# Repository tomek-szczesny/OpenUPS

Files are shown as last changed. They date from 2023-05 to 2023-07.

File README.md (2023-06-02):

# OpenUPS

A universal and versatile high power SBC UPS

## Introduction

**This is a work in progress repository**

More up-to-date information available on Odroid forum:

[Open source UPS design - ODROID](https://forum.odroid.com/viewtopic.php?f=55&t=46481)

License:

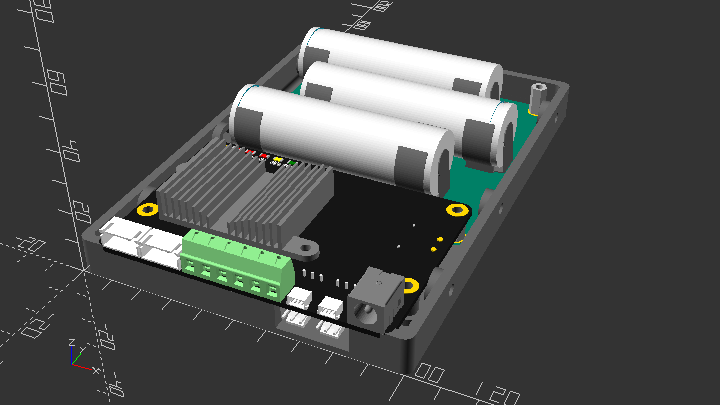
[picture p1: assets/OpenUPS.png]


### Install
```
  git clone https://github.com/tomek-szczesny/OpenUPS.git

```

### OpenUPS Features:
-  Multi SBC support
-  Wide Input Voltage Range: 12V - 24V
-  Multiple Output Voltages: 5V, 12V, Programmable (0-24V) or Vin repeater,
-  Dual SATA power ports, supports 3.5" HDDs as well,
-  Dual 12V Fan ports with PWM control and RPM monitoring,
-  I2C Configuration and Reporting, incl. Battery Voltage, Current
-  3D-printable Custom Cases
   - Drive Bay Case Mount
   - Standalone Case
-  Expandable 3S1P Battery Capacity
-  18650, 20700 or 21700 Cell Support
-  Easy Battery Maintenance

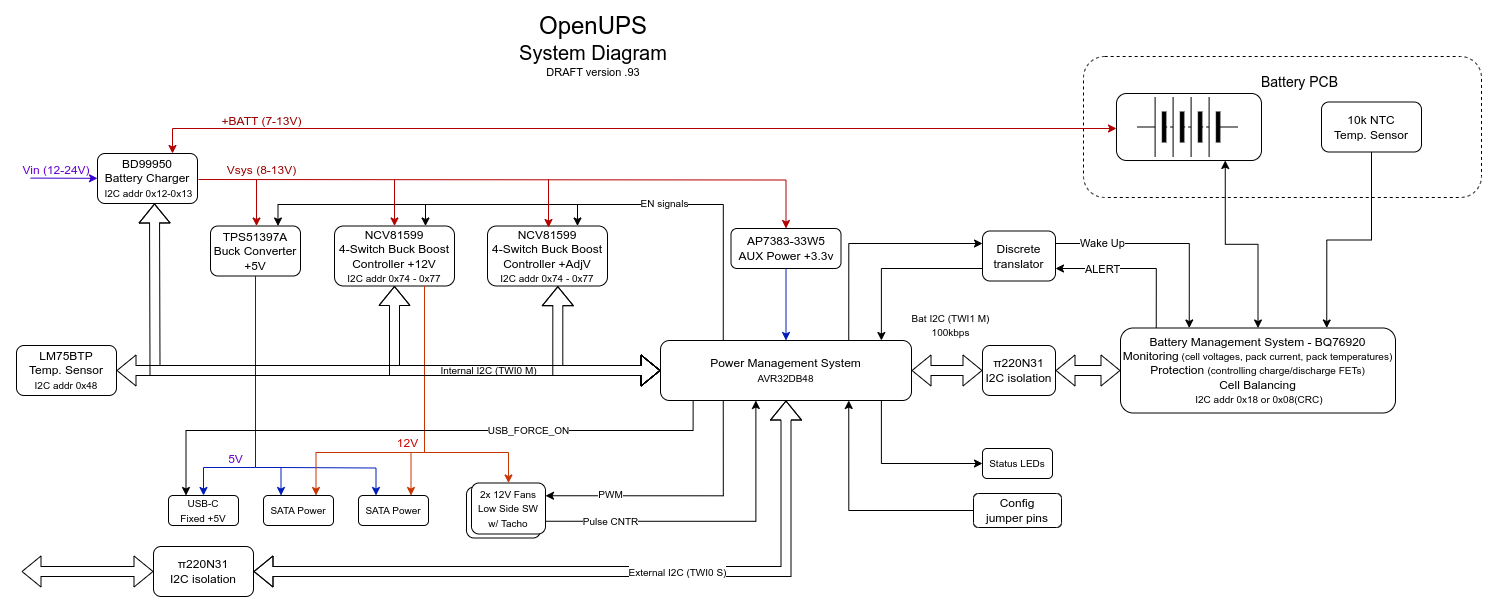
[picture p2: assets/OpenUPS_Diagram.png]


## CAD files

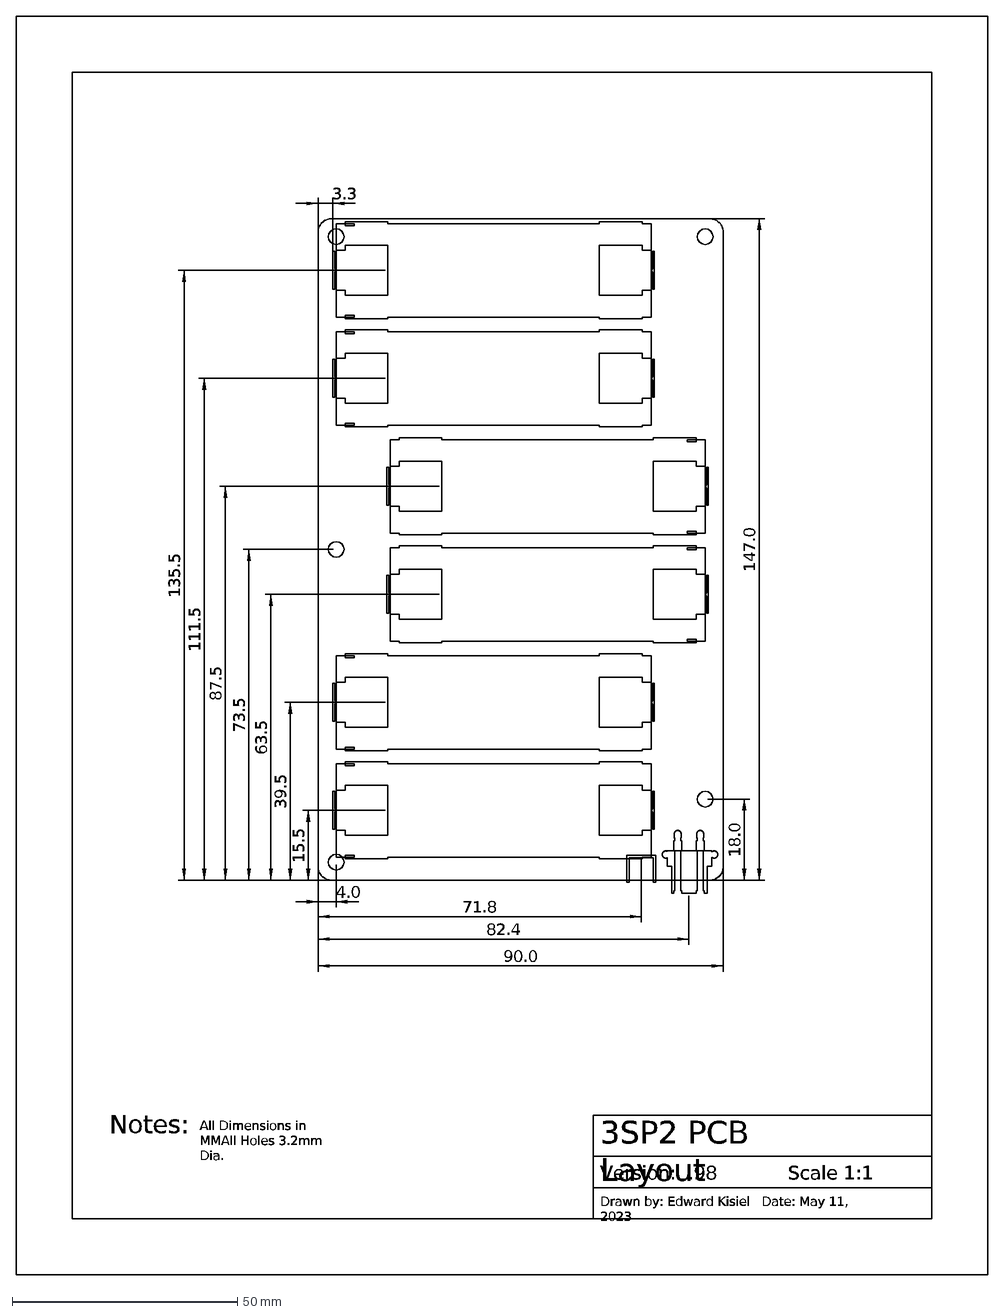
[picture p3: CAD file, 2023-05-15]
case/3S2P_Battery_PCB.dxf
4.0
71.8
82.4
15.5
39.5
63.5
73.5
87.5
111.5
135.5
18.0
3.3
90.0
147.0
Notes:
Version: .98 Scale 1:1
3SP2 PCB Layout
Drawn by: Edward Kisiel Date: May 11, 2023
All Dimensions in MM All Holes 3.2mm Dia.

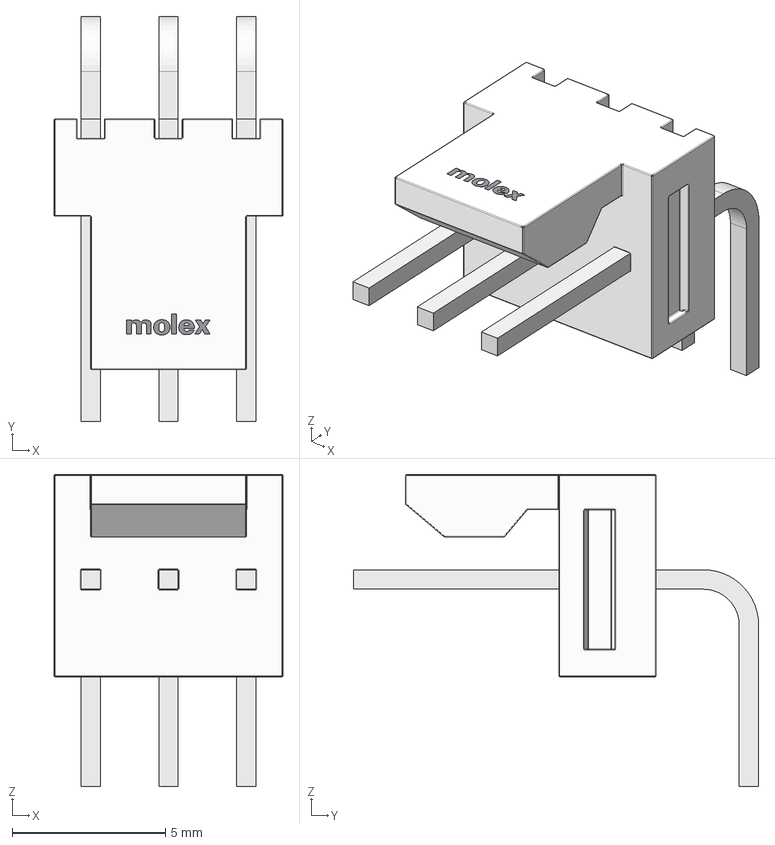
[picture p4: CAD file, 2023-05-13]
hw/OpenUPS_ups/3d/Molex_-_22-05-3031.step
7.47 x 13.2 x 10.2 mm
Molex

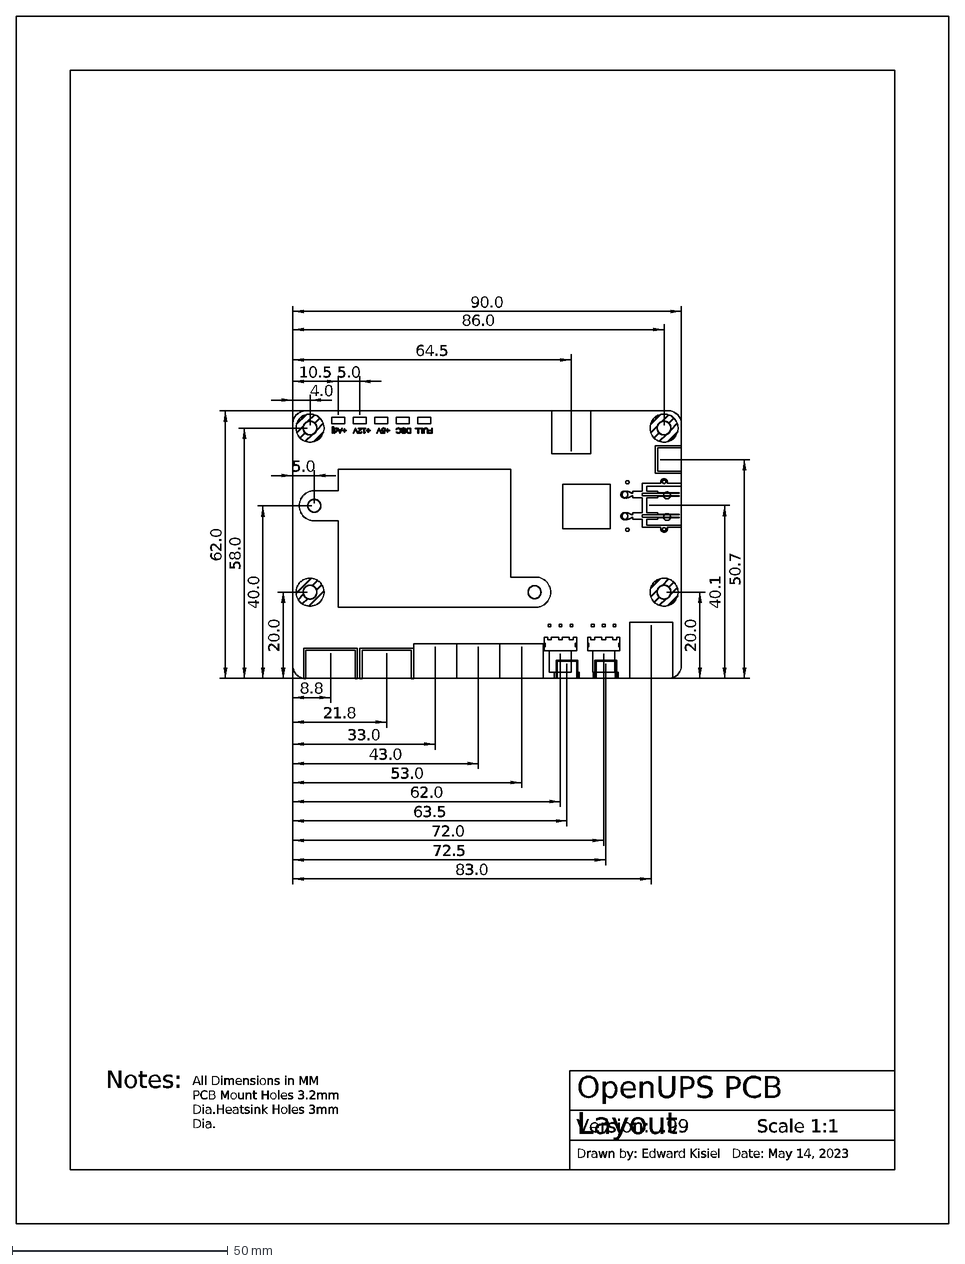
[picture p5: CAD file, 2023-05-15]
case/OpenUPS_PCB.dxf
40.0
58.0
62.0
4.0
5.0
20.0
63.5
72.5
OpenUPS PCB Layout
Notes:
10.5
86.0
90.0
72.0
All Dimensions in MM PCB Mount Holes 3.2mm Dia. Heatsink Holes 3mm Dia.
Version: .99 Scale 1:1
Drawn by: Edward Kisiel Date: May 14, 2023
8.8
21.8
33.0
43.0
53.0
83.0
40.1
50.7
64.5

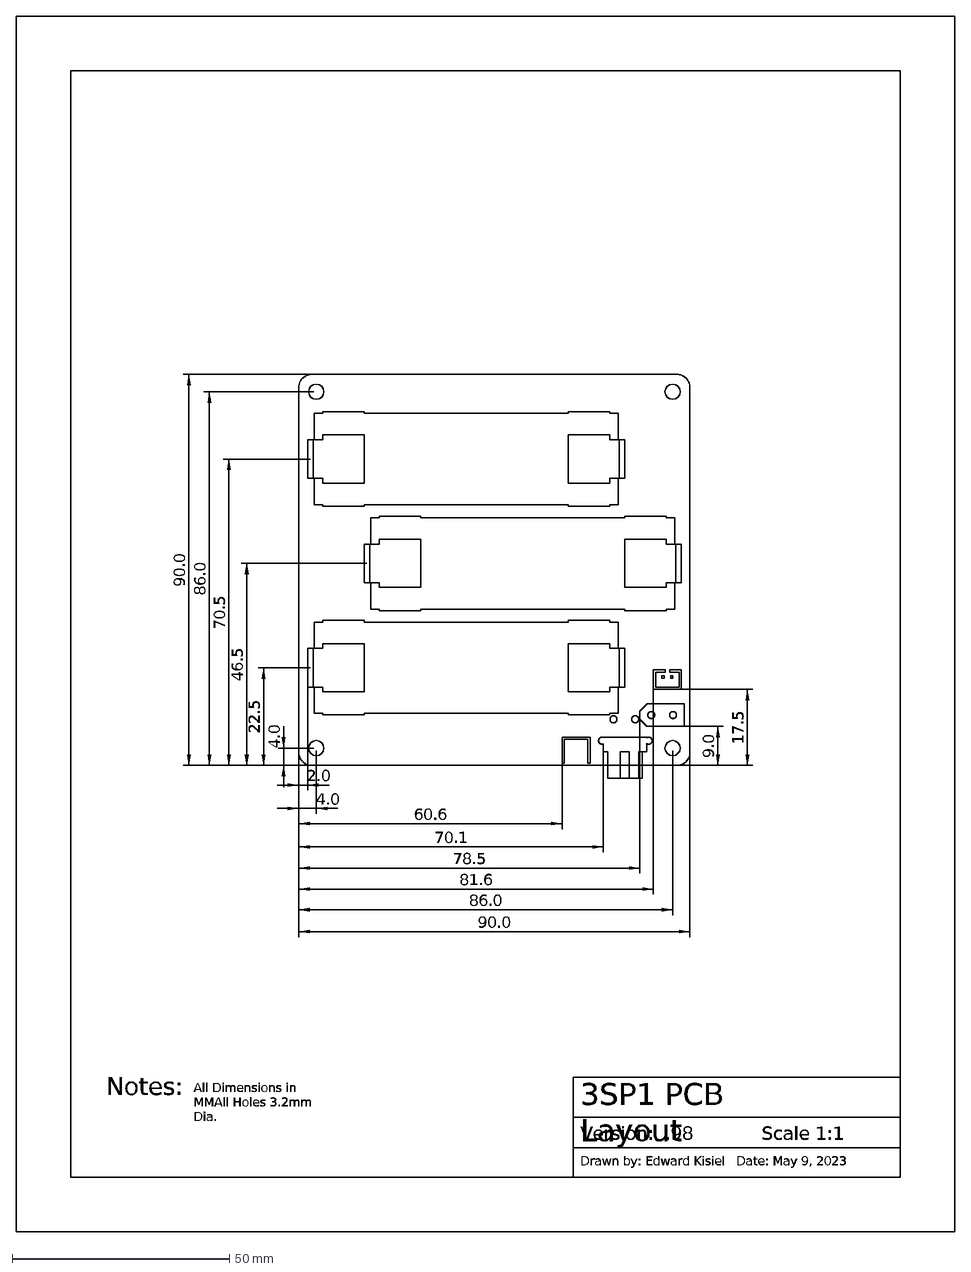
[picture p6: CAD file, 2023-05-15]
case/3S1P_Battery_PCB.dxf
2.0
4.0
60.6
70.1
78.5
81.6
86.0
22.5
46.5
70.5
90.0
Notes:
Version: .98 Scale 1:1
Drawn by: Edward Kisiel Date: May 9, 2023
3SP1 PCB Layout
9.0
17.5
All Dimensions in MM All Holes 3.2mm Dia.

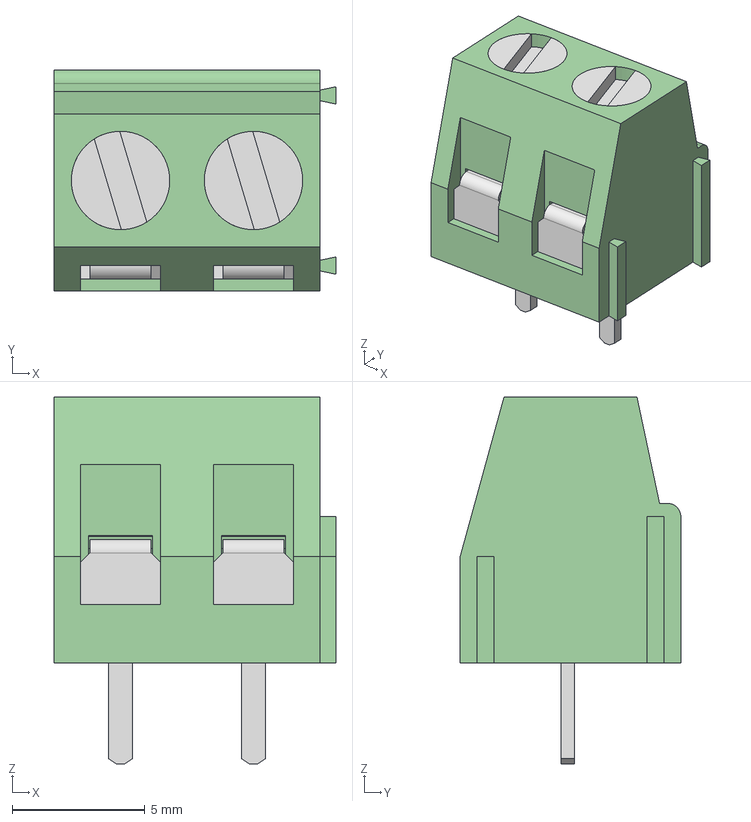
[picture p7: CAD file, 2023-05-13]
hw/OpenUPS_ups/3d/691213710002 (rev1).stp
10.6 x 8.30 x 13.8 mm
6912137100xx_MASS x 2
6912137100xx_VIS x 2
6912137100xx_PIN x 2

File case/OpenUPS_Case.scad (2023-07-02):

/*
    OpenUPS Case Copyright 2023 Edward A. Kisiel hominoid@cablemi.com

    This program is free software: you can redistribute it and/or modify
    it under the terms of the GNU General Public License as published by
    the Free Software Foundation, either version 3 of the License, or
    (at your option) any later version.

    but WITHOUT ANY WARRANTY; without even the implied warranty of
    MERCHANTABILITY or FITNESS FOR A PARTICULAR PURPOSE.  See the
    GNU General Public License for more details.

    You should have received a copy of the GNU General Public License
    along with this program.  If not, see <http://www.gnu.org/licenses/>.
    Code released under GPLv3: http://www.gnu.org/licenses/gpl.html

    202304xx version 0.9 OpenUPS Case
    
    drivebay_ups_top(length=147, width=101.6, bottom_height=12, top_height=14, wallthick, floorthick,
                     pcbsize, pcb_position, batpcbsize, batpcb_position)    
    drivebay_ups_bottom(length=147,width=101.6, bottom_height=12, wallthick, floorthick,
                        pcbsize, pcb_position, batpcbsize, batpcb_position)
    ups_pcb(pcbsize, pcb_position)
    bat_pcb(batpcbsize, batpcb_position)
    battery_placement(bat_layout, bat_num, bat_space, bat_type, bat_dia, bat_len)
    battery_clip(bat_dia = 18.4)
    led(ledcolor = "red")
    battery(type)
    jst_xh(num_pin)
    jst_sh(num_pin)
    jst_ph(num_pin)
    standoff([radius,height,holesize,supportsize,supportheight,sink,style,i_dia,i_depth])
    slab(size, radius)
    slot(hole,length,depth)
    fan_mask(size, thick, style)
    heatsink(type,soc1size_z)xt60(style)
    xt30(style)
    
*/

use <./lib/fillets.scad>;

/* [OpenUPS Case Configuration] */
view = "model"; // ["model", "platter"]
top_enable = true;
bottom_enable = true;
all_connectors = false;
case_style = "drivebay"; // ["drivebay", "mini", "3S1P", "3S2P"]
heatsink_type = "c4_oem"; // ["c4_oem", "xu4_oem"]

ups_pcb_enable = true;
ups_pcb_kicad_model = false;
battery_pcb_enable = true;
rear_wire_feed = false;
bottom_vent = true;
top_vent = true;

bat_num = 3; // [3:3:6]
bat_type = "21700"; // ["18650", "21700"]
bat_layout = "3S_staggered"; // ["straight", "staggered", "3S2P_staggered", "3S_staggered"]
bat_space = 3; // [3:10]

bat_dia = bat_type == "21700" ? 21 : 18.4;
bat_len = bat_type == "21700" ? 70 : 65;

/* [Hidden] */
adj = .01;
$fn = 90;

if(view == "model") {
    if(case_style == "drivebay") {
        // pcb size and placement
        pcbsize = [96, 64, 1.6];
        pcb_position = [2.75, 0, 10];
        batpcbsize = [90, 90, 1];
        batpcb_position = [6, 54, 1];
        bat_position = ([batpcb_position[0]+4,batpcb_position[1]+12,batpcb_position[2]+batpcbsize[2]]);

        if(bottom_enable) {
            color("dimgrey") drivebay_ups_bottom(147, 101.6, 12, 2, 2, 
                pcbsize, pcb_position, batpcbsize, batpcb_position);
        }
        if(top_enable) {
            color("dimgrey") drivebay_ups_top(147, 101.6, 12, 14, 2, 1, 
                pcbsize, pcb_position, batpcbsize, batpcb_position);
        }
        if(ups_pcb_enable) {
            ups_pcb(pcbsize, pcb_position);
        }
        if(ups_pcb_kicad_model) {
            translate([-77,134,10.8]) rotate([0,0,0]) import("lib/OpenUPS_ups.stl");
        }
        if(battery_pcb_enable) {
            bat_pcb(batpcbsize, batpcb_position, bat_position);
            translate(bat_position) battery_placement(bat_layout, bat_num, bat_space, bat_type, bat_dia, bat_len);
            // pillars
            translate([batpcb_position[0]+4, batpcb_position[1]+6,  batpcb_position[2]+batpcbsize[2]]) pillar(5, 8, 0);
            translate([batpcb_position[0]+batpcbsize[0]-4, batpcb_position[1]+6,  batpcb_position[2]+batpcbsize[2]]) 
                pillar(5, 8, 0);
            translate([batpcb_position[0]+4, batpcb_position[1]+batpcbsize[1]-4, batpcb_position[2]+batpcbsize[2]]) 
                pillar(5, 10, 0);
            translate([batpcb_position[0]+batpcbsize[0]-4, batpcb_position[1]+batpcbsize[1]-4, 
                batpcb_position[2]+batpcbsize[2]]) pillar(5, 10, 0);
        }
    }
    if(case_style == "mini") {
        // pcb size and placement
        pcbsize = [96, 64, 1.6];
        pcb_position = [2.75, 0, 10.4];
        batpcbsize = [90, 82, 1.6];
        batpcb_position = [6, 63, 1];
        wallthick = 2;
        floorthick = 1;

        if(bottom_enable) {
            color("dimgrey") drivebay_ups_bottom(66, 101.5, 12, 2, 2, 
                pcbsize, pcb_position, batpcbsize, batpcb_position);
        }
        if(top_enable) {
            color("dimgrey") drivebay_ups_top(66, 101.5, 12, 12, 2, 2, 
                pcbsize, pcb_position, batpcbsize, batpcb_position);
        }
        if(ups_pcb_enable) {
            ups_pcb(pcbsize, pcb_position);
        }
        if(ups_pcb_kicad_model) {
            translate([-80.5,134,11.2]) rotate([0,0,0]) import("lib/OpenUPS_ups.stl");
        }
    }
    if(case_style == "3S1P") {
        
        pcbsize = [90, 82, 1.6];
        pcb_position = [3, 3, 4];
        batpcbsize = [90, 90, 1];
        batpcb_position = [3, 3, 4];
        bat_position = ([batpcb_position[0]+3.5,batpcb_position[1]+12,batpcb_position[2]+batpcbsize[2]]);
        wallthick = 2;
        floorthick = 2;
        gap = 1;

        if(bottom_enable) {
            color("dimgrey") 
            drivebay_ups_bottom(batpcbsize[1]+2*(wallthick+gap), batpcbsize[0]+2*(wallthick+gap), 12, 2, 2, 
                pcbsize, pcb_position, batpcbsize, batpcb_position);
        }
        if(top_enable) {
            translate([0,0,]) color("dimgrey") drivebay_ups_top(batpcbsize[1]+2*(wallthick+gap), 
                batpcbsize[0]+2*(wallthick+gap), 12, 18, 2, 2, pcbsize, pcb_position, batpcbsize, batpcb_position);
        }
        if(battery_pcb_enable) {
            bat_pcb(batpcbsize, batpcb_position, bat_position);
            translate(bat_position) battery_placement(bat_layout, bat_num, bat_space, bat_type, bat_dia, bat_len);
        }
    }
    if(case_style == "3S2P") {
        
        pcbsize = [90, 147, 1];
        pcb_position = [3, 3, 4];
        batpcbsize = [90, 147, 1];
        batpcb_position = [3, 3, 4];
        bat_position = ([batpcb_position[0]+1,batpcb_position[1]+2,batpcb_position[2]+batpcbsize[2]]);
        wallthick = 2;
        floorthick = 2;
        gap = 1;
        
        color("dimgrey") 
        drivebay_ups_bottom(batpcbsize[1]+2*(wallthick+gap), batpcbsize[0]+2*(wallthick+gap), 12, 2, 2, 
            pcbsize, pcb_position, batpcbsize, batpcb_position);
        if(top_enable) {
            translate([0,0,]) color("dimgrey") drivebay_ups_top(batpcbsize[1]+2*(wallthick+gap), 
                batpcbsize[0]+2*(wallthick+gap), 12, 18, 2, 2, pcbsize, pcb_position, batpcbsize, batpcb_position);
        }
        if(battery_pcb_enable) {
            bat_pcb(batpcbsize, batpcb_position);
            translate([batpcb_position[0]+bat_position[0], batpcb_position[1]+bat_position[1], batpcb_position[2]]) 
                battery_placement(bat_layout, bat_num, bat_space, bat_type, bat_dia, bat_len);
        }
    }}

if(view == "platter") {
    if(case_style == "drivebay") {
        // pcb size and placement
        pcbsize = [94, 64, 1.6];
        pcb_position = [6, 0, 9];
        batpcbsize = [90, 82, 1.6];
        batpcb_position = [6, 63, 1];

        drivebay_ups_bottom(147, 101.6, 12, 3, 2, 
            pcbsize, pcb_position, batpcbsize, batpcb_position);
        translate([0,-10,26]) rotate([180,0,0]) drivebay_ups_top(147, 101.6, 14, 12, 2, 1, 
            pcbsize, pcb_position, batpcbsize, batpcb_position);
    }
    if(case_style == "mini") {
        // pcb size and placement
        pcbsize = [94, 64, 1.6];
        pcb_position = [2.5, 0, 9];
        batpcbsize = [90, 82, 1.6];
        batpcb_position = [6, 63, 1];
        wallthick = 2;
        floorthick = 1;

        drivebay_ups_bottom(65, 95, 12, 2, 2, 
            pcbsize, pcb_position, batpcbsize, batpcb_position);
        translate([0,-10,24]) rotate([180,0,0]) drivebay_ups_top(65, 95, 12, 12, 2, 2, 
            pcbsize, pcb_position, batpcbsize, batpcb_position);
    }
    if(case_style == "3S1P") {
        // pcb size and placement
        pcbsize = [90, 82, 1.6];
        pcb_position = [3, 3, 4];
        batpcbsize = [90, 90, 1];
        batpcb_position = [3, 3, 4];
        bat_position = ([batpcb_position[0]+4,batpcb_position[1]+12,batpcb_position[2]+batpcbsize[2]]);
        wallthick = 2;
        floorthick = 2;
        gap = 1;
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

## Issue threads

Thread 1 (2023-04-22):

Battery Module requirements

tomek-szczesny, 2023-04-22:
Here are some requirements towards the battery PCB. Any changes will be applied to this "post" in the future.

The battery module consists of three 21700 cells connected in series, placed in dedicated cell holders. The module PCB also provides basic protection against overcharging, overcurrent, overheating, as well as balances the cells.

Functional requirements:
- Three 21700 cells connected in series
- Short circuit protection at 15-20A
- Discharge overcurrent protection at 9 - 12A (above 200-500ms)
- Charge overcurrent protection at 3 - 4A
- Overvoltage protection within 4.0 - 4.2V per cell
- Undervoltage cut-off at 2.9 - 3.2V per cell
- Cell balancing at any reasonable rate (10-100mA?), without risk of overheating
- Thermal cell protection within 45-55 deg C range
- Battery pack must recover from any fault conditions without user intervention

Mechanical requirements:
- 2-layer, 35um PCB with SMD components only, on top side only (bottom must be flat and fully isolated)
- PCB dimensions and cell layout TBD
- Cell orientation is arbitrary but must be clearly marked on top silkscreen

Parts:
- Battery holders: Keystone 246 (product catalog and layout recommendations [here](https://www.keyelco.com/userAssets/file/M70p39-42.pdf)
- BQ77915 family cell protector and balancer (specific part numbers to be selected)
- 2x NMOS TBD (adapted from UPS schematic)
- 0603 passives, except current sense resistor which may be larger

tomek-szczesny, 2023-05-07:
After a bit of discussion and market research (thanks @hominoids!) we have decided to embrace a new approach in a battery carrier board design.
As per Issue #15, there is a demand for support of all sorts of battery chemistries. Also the battery charger has changed (#24), allowing us for greater flexibility and control of a charging process.

Thus the new Battery Module will consist of programmable parts that may support any kind of rechargeable cells. It will be accompanied by a cheap microcontroller, overseeing the safety of a battery pack.

And finally, two battery modules are foreseen, with three or six rechargeable cells in total. However their schematics will only differ by cell count.

-----

The battery module consists of three rechargeable cells of any chemistry, connected in series, placed in dedicated cell holders. The module also provides basic protection against overcharging, overcurrent, overheating, as well as balances the cells.

The battery module will support one of the two assembly variants:

-For 20700 or 21700 cells (Keystone 246)
-For 18650 cells (Keystone 254)

Functional requirements:

- Three cells connected in series
- Protection features programmed into a microcontroller (outside the scope of PCB design)
- Battery protection chip and microcontroller joined together by I2C (examples available in BQ datasheet)
- Microcontroller's UART port exposed to an external port (Connector type TBD)
- Exposed UART interface must be isolated (different ground levels on both sides are to be expected)

Mechanical requirements:

- 2-layer, 1mm thick, 35um copper PCB with SMD components only, on top side only (bottom must be flat and fully isolated)
- Non-plated holes are acceptable
- 4-layer PCB possible if deemed necessary
- PCB dimensions and cell layout TBD
- Cell orientation is arbitrary but must be clearly marked on top silkscreen

Parts:

- Battery holders (datasheets contain recommended layouts):
-- [Keystone 246](https://www.tme.eu/Document/e5772600337aeb23fa2c0e3e182b7b5b/246.pdf)
-- [Keystone 254](https://www.mouser.pl/datasheet/2/215/254-1662482.pdf)
-- [BQ76920](https://www.ti.com/lit/ds/symlink/bq76920.pdf?ts=1683379604037) family cell protector and balancer (Specifically, BQ7692006PW)
-- The cheapest AVR microcontroller with 8 pins, or more if needed (For example Attiny402)
-- 2x NMOS for disconnecting a battery in case of failure - TBD (adapted from UPS schematic)
-- 0603 passives, except current sense resistor which may be larger

----

6-cell module is meant to be electrically identical, except each cell is replaced by two cells in parallel (So called 3S2P configuration). Obviously the board size will be different, and so a separate mechanical drawing will apply.

tomek-szczesny, 2023-05-10:
As of today, here is the mechanical drawing of the 3S1P PCB:
https://github.com/tomek-szczesny/OpenUPS/blob/ups_encl/case/3S1P_Battery_PCB.dxf

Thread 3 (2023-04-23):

Battery - UPS interconnection

tomek-szczesny, 2023-04-23:
For now I've added XT60PW-M as a schematic placeholder until we settle on the target PCB interconnection.

tomek-szczesny, 2023-06-06:
Can't believe this is still an issue. ;)

I just added a screenshot of the current state of PCB design on Odroid forum.
I'm not diving into a PCB design for another few days so I'll take this opportunity to discuss the possible improvement in terms of the PCB layout.

Let's assume the upper edge on this drawing is the front side of UPS in mini case. Where USB-C and LEDs are.

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

Long story short, I'd like to discuss the possibility of placing all three battery connectors on the front: Heavy lifting XT30, two-pin JST for pack sense and Qwiic for temp sensor I2C.

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

The obvious drawback is having all these connectors on the front of the device. I can't tell how much worse this is than having them on the side, the question is open to the broader public of potential users.
And this solution assumes that some connections between both PCBs of a drivebay build will be discrete, using separate wires. Personally I don't see it as a problem, given how much time we've already invested seeking for a suitable board to board connection.

There are a few reasons for this layout:
- All these connectors and BMS work with a "Different GND", or BATT-. With BMS fitted somewhere in that corner, it will minimize the area of foreign voltage domain. Note that GND is also our primary heatsink, so we want to maximize it.
- Less footprints, more space. With one XT30 less we can actually place Qwiic on top of it.
- Bottom side XT30 and JST pin holes will be extended with wire pads on the bottom side. Same for BAT PCB that may have the same pattern for the same purpose. That is, if we are willing to accept soldering four wires in drivebay build. Heck, we can as well go all in and do all the 7 connections as discrete wires while we're at it.
- I2C is closer to AVR, and I2C isolator may be placed away from the BMS (next to LEDs)
- More space for charger heatsinking pours.

hominoids, 2023-06-07:
Replacing the inward facing XT30 for soldered wires is not a big deal but moving the other XT30 to the front really undermines it's purpose.  If it has to be done I understand but I would then advocate to remove it entirely because there would no use case for it in the front and using a pigtail feed through the back would be the better and preferred battery connection IMO.

tomek-szczesny, 2023-06-08:
Thanks for your input, that's exactly why I'm asking. Sometimes I know we had decided something but can't remember why.

Here are two new options to consider. Both are almost the same. Single XT30, 2-pin JST and Qwiic are placed on the right hand side. Two bottom side pads, 5x10mm, can accept very thick wires for drivebay build.
The difference is in 6-pin mixed I2C and bat sense connector, dedicated to drivebay build. Either a THT bottom side JST, or top side SMD FPC ribbon with 1mm pitch (TE 84953-6).
Six pin link would be "4S ready".

I think ribbon makes more sense due to its high flexibility, should be easy to hook up between both PCBs even after they are mounted in the drivebay box.
The downside of this solution I can see for now are XT30 and wire pads overlapping on the bottom side. It's not a big issue considering two overlapping XT30s were a base solution we're trying to improve now.

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

hominoids, 2023-06-08:
I like both  solutions and can live with either one.   IMO the JST connector makes a little more sense then the ribbon cable for a couple reasons.  The first is that they are tougher and can take more abuse and are equally easy to hookup.  When silicon insulated wire is used they may be more flexible then a ribbon cable and can be acquired anywhere and/or easily made to any length needed on the fly.  The JST could also be used to extend the standalone case to support 4S, or use the combined connector if preferred, by soldering wires to the pads and running a pigtail through a side or rear case wire slot.  I cannot tell the size of JST your proposing but a JST-PH(2mm) would be my choice. FYI, I have a 100' roll of high strand silicon insulated 24ga wire that was incorrectly sent to me that could be used to make JST cables once  I order up a larger JST connector kit(5-8pin).

tomek-szczesny, 2023-06-08:
OK so how about this. A unified 6-pin connector for standalone and drivebay battery packs in JST-PH format. Two footprints, horizontal on the bottom side (purple) and vertical on the top side (teal) share the same holes. Above I've drawn an example PCB layout on BAT PCB, with vertical and horizontal SMD JST footprints (horizontal being closer to the edge). As far as I can remember we gave up XT30 on BAT PCB at some point and decided to have it pigtailed.

That is also the most space efficient solution to date. The question is, can we afford the top side vertical JST connector on a UPS PCB?

I would appreciate if you took over the JST cable making duty. :)

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

hominoids, 2023-06-08:
That sounds good, I like the solution.  FYI, the [last discussion](https://forum.odroid.com/viewtopic.php?f=55&t=46481&start=151) about the battery connections had a rear facing and vertical XT30 with an additional solder pad set.  The rear facing was for 3S2P drive bay case mounting, the vertical was for standalone and drive bay case use, as were the solder pads.  Now, that all got set aside IMO when we changed and moved the BMS to the UPS PCB.  Since there is plenty of room the question now is what to include on the battery PCB and where.  I don't see any reason we cannot keep the same configuration but I'm open to other suggestions.  You can also view 'all connectors' in the OpenScad model to visualize the current setup.

tomek-szczesny, 2023-06-15:
As far as I can remember, in every drivebay configuration our top concern was height of a battery pack. We slimmed down PCB to 1mm and even the case floor where PCB is supposed to be, just to barely fit into the drivebay format height.
There are no SMD XT30 connectors on the market, I believe, and we can't use THTs in a drivebay battery pack, because it has to lie flat on the case bottom.

Digesting all these facts, in my mind, the conclusion is this: We can add XT30 connectors to battery PCBs, but only if the cell size will be limited to 18650, or battery case size enlarged over drivebay specs.

XT30 is not needed for integrated drivebay OpenUPS build because solder pads make more sense in this build.

3S2P battery pack, if we think about it, doesn't need to fit into a drive bay, because the standalone OpenUPS in mini case won't fit the drive bay either. It will be a standalone modular device, without any claims of fitting anywhere in particular. However it would be nice if they were stackable in an elegant fashion.

So here's what I propose:
- OpenUPS in drivebay case as planned before, interconnected with short 6-pin JST cable and two soldered wires
- OpenUPS mini, with XT30 input and 6-pin JST connector on its side,
- Standalone battery packs: 3S1P and 3S2P, the latter having two PCBs inside. Both should have XT30 and JST exposed... perhaps on their side?

I forgot how much fun sketching is. This is my concept art of standalone OpenUPS. :)
There is nothing against 3S4P at this point, if someone really likes the idea. The only limit are 8 thermal sensors, and I foresee one for each 3S1P PCB.

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

hominoids, 2023-06-15:
That sounds good.  I have not started work on the dual PCB 3S2P case because I'm waiting for the layout to settle more.  I'm not worried about it because the current configuration and sense line setup allows for any number of different battery pack configurations.  Once we have a finalized layout I'll put the time into figuring out other case possibilities.

tomek-szczesny, 2023-06-18:
Could you help me determine the "correct" XT30 pinout? The footprint has plus and minus marks on a silkscreen layer but I'm not convinced they are correct. This is a male XT30 on a bottom side of a PCB (as seen from top). I heard the actual connectors have polarity markings on them, which would be nice to follow.

hominoids, 2023-06-18:
That appears to be correct.  The + side is on the flat side of the connector and the - is on the keyed side as shown in the photo of XT60's which have the same orientation.  Ignore the wire position in the photo, it's wrong.
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

hominoids, 2023-06-18:
I just noticed there are two plus symbols so let me clarify, I believe the plus side should be at the square pad position.

tomek-szczesny, 2023-06-20:
Hmm my previous screenshot must have been confusing. It was showing the bottom side silkscreen, but seen from the top side.
Here are two renders of the same spot with no changes. As long as your 3D model is correct, and indeed flat side is a plus, then I think the square pad should be a minus.
Which is also in line with a Kicad built-in XT30 footprint.

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

hominoids, 2023-06-20:
That is correct as indicted in the picture below.  The XT30 minus mark can be seen on the keyed side attached to the black wire and the red wire is attached to the flat side.  I think your good.
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

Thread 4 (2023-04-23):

Battery charger - possible reverse current

tomek-szczesny, 2023-04-23:
A case have been found in which a battery may discharge into 12V output via charger's buck converter.
To be addressed later - perhaps top level architecture will prevent this from happening somehow.

tomek-szczesny, 2023-05-01:
No Buck, no problem.

Closed 2023-05-01.

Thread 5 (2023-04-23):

Linux software

tomek-szczesny, 2023-04-23:
We will need a suite of programs for basic communication with OpenUPS via I2C port.
Fortunately enough it may be generic for any platform and communicate via `/dev/i2cx`. I guess?

I think we should lean towards a daemon service `openupsd` that will interact with i2c, and a client `openups` that may be used with no special privileges.

Should be written in C/C++ and without exotic libraries (preferably no libraries outside gcc standards).

Some things those programs will do:

**openupsd**
- exchange data between OpenUPS hardware and `openups` client
-  Makes sure write requests are sane
- Support triggers (No AC, Batt voltage < 10V, etc.) and launch a defined script on first match. To be defined as command line params (easier to deal with in service file)

**openups**
- syntax: `openups [FLAGS] REG1 [VAL1] REG2 [VAL2]...`
- --read (-r) : reads `REGn`, one or more. Each value in new line
- --write (-w) : writes `VALn` into `REGn`.
- --verbose (-v) : (script-friendly output by default)
- --info (-i) : spits out everything it knows (-v implied)
Bonus points for:
- --interactive : with menus, graphs and ascii-art spinning fans, using notcurses library 🤣

No case sensitivity, supports both dots and commas as numerical separators.
`openups` should parse its command line parameters and do nothing (exit with error) if anything is ambiguous. We don't want anyone to raise output voltage by mistake.
Exit codes should indicate what went wrong (No answer, wrong answer, garbage input etc).

We will define mnemonics for register names to make life easier for everyone.
For example FAN1, when read will return RPM, and when written will set PWM.

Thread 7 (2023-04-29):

External I2C connection closes a ground loop

tomek-szczesny, 2023-04-29:
Ah, snap. We may need to implement I2C isolator, or some passive hacks to prevent that from happening.

tomek-szczesny, 2023-04-29:
On a related note, we can use unique AVR DB feature: A secondary voltage input for selected group of IO pins. It so happens that those pins include I2C Slave interface. Thus, we can use supply voltage coming from Qwiic for this group of pins.
This way, external I2C port will be compatible with any voltage levels up to 5V.

Hmm that doesn't help with the main issue here though.

tomek-szczesny, 2023-04-30:
Oh yeah...
https://www.redeweb.com/en/articulos/aislamiento-sencillo-del-bus-i2c-mediante-componentes-discretos/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

Guess we won't be needing that VCCIO2 feature after all.

tomek-szczesny, 2023-05-01:
I found out that commercial, bidirectional I2C isolator (remember clock stretching) are generally unavailable and expensive AF.
I designed a optocoupler-based workaround that looks huge, power hungry and not that competitive in terms of price. Only when Vishay optocouplers are sourced from TME (3x cheaper for whatever reason!?), it barely makes any sense.
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
And then I found this chip, which is a direct replacement of AD and TI counterparts.
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

Looks like the problem is solved.

Closed 2023-05-01.

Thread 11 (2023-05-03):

Use THT electrolytic caps for easier repairs

tomek-szczesny, 2023-05-03:
As stated in the title, I know exactly how hard it is to remove those SMD cans, and solder in new ones on a crowded PCB.

@hominoids, what is a safe estimate of a UPS PCB top side clearance? Can we use 11mm tall capacitors?

hominoids, 2023-05-03:
The red rod is 11mm tall so an 11mm tall capacitors will fit without an issue.
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

tomek-szczesny, 2023-05-07:
This has been decided that we'll use THT electrolytic caps up to 7mm high, on a bottom side of UPS PCB, where applicable.

tomek-szczesny, 2023-05-10:
Seems like there is an awful lot of caps fitting into 6.3mm diameter, 7mm height, 2.5mm pin spacing. Here is one I have selected for Vbus and 12V:
https://www.mouser.pl/ProductDetail/Rubycon/25ZLG47MEFC6.3X7?qs=T3oQrply3y99xHUW5IeoPQ%3D%3D

The 1000h life expectancy is specified for 105C ambient temperature, maximum voltage and constant current cycling. After that time the capacitor is not dead, just degraded. At 45C ambient temperature alone, we should be expecting 2^6 times longer life, which is about 7 years. In practice, longer than that due to gentler treatment they will be experiencing.
Source: https://www.xppower.com/resources/blog/electrolytic-capacitor-lifetime-in-power-supplies

Closed 2023-05-17.

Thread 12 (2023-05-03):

Polyfuses for each output

tomek-szczesny, 2023-05-03:
I'm thinking about:
- 5V: 4A
- 12V: 5A
- Vadj: 4A
- USB 5V: 4A
- SATA: No fuses. After all, motherboards don't have special fuses for SATA drives.

tomek-szczesny, 2023-05-05:
So far I've implemented:
- PTS18126V260 for 5V output (screw terminal). Passes 5A min, trips at 8A in 2.5s.
- 0ZCF0200AF2C for 12V and Adj outputs. Passes 4A, trips at 8A in 5s.

I don't like the latter, it's huge.

USB will be protected by current limiting switch.

tomek-szczesny, 2023-05-16:
Studying PTH fuses in greater detail, they do not respond fast enough, and their current rating is not just a single number that says it all. 5A fuse is guaranteed to pass 5A, but will act on 25A after 2s, for example.

After some more thought, I'm thinking all power converters shall assure sane current output limits, each according to its capabilities. Fuses are supposed to protect outputs against converter fault, mostly. Thus, I think blow-fuses are justified here.

https://www.tme.eu/en/katalog/smd-fuses_100131/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

At the same time, we don't want to pop the fuses during "nominal working conditions", which also includes end user doing short circuit. So it may make sense to use time-lag fuses:
https://www.tme.eu/en/katalog/smd-fuses_100131/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

1206 pads will let us pick any fuse we like for each output.

tomek-szczesny, 2023-05-17:
The solution that I just adapted will surely blow fuses due to output capacitor discharge on short circuit.
So it makes sense to move fuses between converter output and capacitor bank.
All converters support controlled ramp-up so fuses shouldn't blow on start-up.
Probably a good idea then. There's no reason not to use fast acting fuses now.

tomek-szczesny, 2023-05-18:
It gets complicated because we have multiple outputs. Let's consider this scenario:
```
Converter --> fuse --> caps +--> 5V screw terminal output
                            +--> 5V SATA output
                            +--> USB switch with current limit --> 5V USB output
```

Screw terminal output and SATA output are not protected against shorts, shorting one will affect all 5V outputs. This is also true for 12V output. On the other hand, that is to be expected from a multi-voltage computer PSU.

I think this is acceptable, as only USB is considered a "user accessible output" for daily use. All the remaining ports should be treated as semi-permanent. Just like typical computer architectures do.

tomek-szczesny, 2023-06-29:
Looks like we can afford eFuses after all:
https://www.mouser.pl/c/?q=TPS25947
Some $1.5 for an adjustable FET-based fuse, with digital signaling and so on.

Those could be used directly on screw terminal outputs, regardless of capacitor banks and so on.

USB got its own protection, and other misc outputs (fans, SATA) can get blow fuses or PTCs, or no protection at all. Taking Odroid H3 schematic as a reference, they have no overcurrent protection on fan or SATA outputs. So probably SMD blow fuses will be more than adequate.

f1vefour, 2023-07-01:
What is the function of Vadj?

tomek-szczesny, 2023-07-02:
> What is the function of Vadj?

Adjustable (programmable) output.

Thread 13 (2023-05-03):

USB PD output

tomek-szczesny, 2023-05-03:
Since we've committed to USB-PD output, it'd be nice to actually implement it at some point.

The problem is, each user may have different expectations for this port. Someone may mistake it for a power input. Others may wish to charge their laptops off it. All compliant devices require special signalling on CC pins to source current from USB-C, and conversely, should offer a handshake, otherwise we may run into situation of two chargers playing tug of war.
There must be some chip or another to advertise supported modes of operation and avoid damage.

Ideally we want a chip that does all that: Advertise voltage and power options, limited to some sane value like 30W, and drives a switch or a built-in power converter.

One solid candidate is [TPS25740](https://www.ti.com/lit/ds/symlink/tps25740.pdf), although it seems that it must be accompanied by a separate voltage converter it could control directly. This may be arranged, but again, cost, space, all that stuff.

We could limit the scope of USB PD to 5V output only (that was the original goal), but I can't find chips with such limited scope.
The only suitable chip for this task we've identified so far is [IP6518](http://www.injoinic.com/wwwroot/uploads/files/20200220/c55f78d32299df716a7c737ce28c2af2.pdf) that is hard to source outside Sinoverse. A Western equivalent would be literally perfect.

To wrap it up:
- We need a chip that can do the talking via DP, DM, CCs
- A solution for generating required output voltages (optionally, we've got 5V source already and 5V-only mode is also fine)
- We've got 5V and 12V high-current sources at our disposal, and 9-24V unregulated rail

hominoids, 2023-05-03:
Something similar to the Ti chip is the [onsemi FUSB15101MNTWG](https://www.digikey.com/en/products/detail/onsemi/FUSB15101MNTWG/17053360).

This might be the perfect solution though since it appears to be fully self contained, just add power, [Infineon CYPD3177-24LQXQT](https://www.digikey.com/en/products/detail/infineon-technologies/CYPD3177-24LQXQT/10238323)

tomek-szczesny, 2023-05-04:
Good grief, my head will explode from all this new information.
[Here](http://ww1.microchip.com/downloads/en/appnotes/00001953a.pdf) is a a very nice Microchip paper on USB-C, which goes into the details of how exactly CC pins work.

Long story short, PD is not mandatory and not needed for what we're trying to achieve.

So this is what happens:
- DFPs (Downstream Facing Ports) advertise their current capability by pulling up both CC pins. For 5V 3A output, that's 10k pull-up to 5V (Table 6).
- 3A is the maximum VBUS current without DP
- UFPs implement pull-down resistors (or other means) in order to complete a voltage divider network
- Cable Attach Detection is a mandatory feature that works by sensing CC pin voltage
- If 3A is advertised, CC voltage under 2.75V means the connection is established and valid.
- Both CC pins must be monitored, and the results OR'ed (voltage drop on one pin is enough)
- UFP (The device) is responsible for limiting its current draw, not the source
- That means we may as well offer up to 5A for non-compliant devices, and still be compliant with USB specs.
- "5V to VBUS may only be applied when a valid cable attachment is detected. This prevents two downstream facing
ports from back-driving current into each other."

So if my understanding is correct, all we need is:
- CC pins pull-ups
- Two comaparators with wired-OR that monitor CC voltages
- a PMOS switch (or dedicated USB load switch).
...and we should be all set.

tomek-szczesny, 2023-05-04:
Ah, here's a good candidate: A dedicated USB switch, 3A (limit above 3.5A), active low enable signal, $.50:
https://www.mouser.pl/ProductDetail/Diodes-Incorporated/AP22814BW5-7?qs=lqAf%2FiVYw9gFAqm%252B3YvdqA%3D%3D

Unless we do want to support those non-standard output currents:
4A: https://www.mouser.pl/ProductDetail/Diodes-Incorporated/AP22800HB-7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

Closed 2023-05-10.

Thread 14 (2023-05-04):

Fuel Gauge

tomek-szczesny, 2023-05-04:
Fuel Gauge chips are expensive, and the market is dominated by ICs for single cell systems.
This is not a feature that is in demand or necessary, just leaving it here as a possible improvement for the future.

A crude fuel gauge could be implemented on AVR (that already monitors the battery current).
But it should not be attempted at least until the current measurements are proven to be reliable enough.

paulcrawford, 2023-05-04:
My data collector system that runs in C on my N2L does complete management of an LiFePO4 battery (24V 70Ah) including charging and load monitoring both voltage and current that runs a 750W three phase motor via a 240VAC inverter and single phase to three phase VFD. It includes individual cell protection for low voltage and high voltage and temperature. I use 2 industrial grade current shunts to measure battery output and input in addition to charging current from a 240VAC charger specifically for LiFePO4 batteries.

The above is of course a much larger scale of power than OpenUPS but here is an example for 10A:

https://canada.newark.com/canadian-shunt/la-10-100/base-mounted-dc-shunt-100mv-10a/dp/73K4798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

It is of course very bulky but also very accurate.

The software I have developed does not care about the scale of power being monitored so perhaps could be adapted to the OpenUPS AVR MCU.

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

tomek-szczesny, 2023-05-04:
Battery current monitoring is already implemented and will be available directly at AVR ADC input.

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

Its range includes 5A charging and 15A discharge current. It is deliberately slowed down by low pass filter to give more meaningful results when probed less often. I'll tune this filter's corner frequency below Nyquist frequency later, so we can reliably integrate current in either direction.

If your software can monitor battery charge and return its status in % or Wh, and require no prior configuration of cell capacity, that would be perfect. Manual battery charge configuration is also possible via I2C commands.

All the safety features are already assured by other mechanisms in the system, but thanks for mentioning them. AVR will have no access to individual cells, only the two battery leads.

paulcrawford, 2023-05-04:
When I started developing my system, about 20 years ago, it was based on flooded lead acid batteries. Then I moved on absorbed glass mat (AGM) batteries, which are still essentially lead acid. A lot of effort went into developing capacity tests that could determine the Peukert constant for the batteries. Knowing that constant allows the calculations for per cent capacity remaining. But as the actual capacity keeps changing over time the capacity test needed to be done to determine the new values.

With the advent of Lithium batteries, the Peukert constant became much lower and predictable enough to not require the sophisticated capacity tests any more and if the cell is of good quality the capacity stated on the label is what you get with much less degradation over time as with lead acid. For my needs, house batteries on a boat, the LiFePO4 variety of Lithium is the best from a safety point of view. @Hominoid did mention possibly using LiFePO4 cells. Has a final decision been on that yet? They do have different characteristics than other LiIon cells but I am sure you have considered that already.

The BQ77915 looks interesting but the maximum voltage and current limits, 22V and 4A are too small for me. Perhaps they make a high power version as well. I use latching relays rated at 50A to cutoff load and charging when required using an independent 8 channel analog to digital voltmeter and 4 DS18B20 temperature sensors to monitor 8 cells. Experience by others shows that with proper initial top balancing there is really not much need for continual balancing for the application I have. The OpenUPS is different and you get balancing already with the BQ so that should be fine.

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

tomek-szczesny, 2023-05-05:
LiFePO cells were discussed and it has been concluded that those would require a separate, new design of the cell carrier board (different protection mechanism). With their poor output current rating, the functionality of OpenUPS will be limited, but still should work nevertheless, for applications up to around 40W.
6-pack LiFePO4 would make more sense, which is also possible at this point.

What I was hoping for is a coulomb counter algorithm. A piece of software than can track charge flowing in either direction, and thus learn maximum battery charge, as well as predict its state. The "learning" part is important, as cells come in great variety and condition.

We're only after a very rough estimate of a battery charge. This could enable a user to script their way into shutting down a server when estimated battery charge is below 15%, for example.

The only benefit of using a dedicated chip is that it has a proprietary algorithm inside it.

tomek-szczesny, 2023-05-10:
The coulomb counter has been included in the battery pack (#1).
Charger circuit (#24) has "Learn mode" which will be used for measuring battery capacity.
I think this is good enough for our purposes.

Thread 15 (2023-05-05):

LiFePO4 support

tomek-szczesny, 2023-05-05:
In order to support this different cell chemistry, we should consider:
- Mechanical concerns, how big LiFePO4 cells in their typical sizes are we able to fit,
- A separate 3S1P and 3S2P PCBs with appropriate pack protection (different voltage and current limits)
- Additional options in AVR Firmware (different target voltage of a charger)

Personally I don't plan on using LiFePO4 cells, so everyone is welcome to contribute to this effort.

hominoids, 2023-05-05:
I am interest in LiFePO4 support and will work on the mechanical and electrical issues.

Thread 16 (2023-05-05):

LED indicators

tomek-szczesny, 2023-05-05:
I keep forgetting about them.

I'm thinking about the following LEDs, driven by MCU:
- green Batt LED: Blinking when charging, solid when charged
- red Batt LED: Blinking when discharging, solid on error (no battery, most likely)
- Green LEDs "power good" for each of three voltage converters: 5V, 12V, Adj
(Even though some power converters have Power Good outputs, I think it should be driven by a microcontroller)

We could add a "power on" LED but that feels redundant - at least one Batt LED will be on anyway.

Now when we need extra 5x GPIO, the real question is whether we switch to 48-pin AVR, or add I2C port extender...

hominoids, 2023-05-05:
"Power on" is probably not needed if there are three "power good" LED.  To avoid increasing pin count the "power good" could be AND together using one LED and the "charging" and "discharging" could be combined too. Off when charged, solid when charging and blinking when discharging.

tomek-szczesny, 2023-05-06:
I made a little search and concluded it's far cheaper to use a bigger AVR than adding a dedicated external LED driver.
By "Bigger AVR" I mean a 48-pin package, which has more pins, but is physically smaller than 28-pin variants.
We already have too few pins at this point, so we may as well commit to this change already.

There is also a way of connecting 6 LEDs to 3 GPIO, which would require time multiplexing to control them, but let's not get THAT cheap.

I suppose we can allow ourselves to provide as many LEDs as we deem necessary and practical.  We don't want to remove any useful indicator, but at the same time we don't want to create an interface that is too cluttered and hard to read.

"Power good" LEDs are meant to show not only that the output voltage is within limits, but also indicate which power outputs are on. I think I'll let the user switch power outputs on and off via I2C commands. On a second thought, there is no good reason to insist on driving these LEDs by MCU, so 5V power good will be driven by 5V Buck directly.

Anything else we wish to notify a user about?

tomek-szczesny, 2023-05-06:
I added 5 LEDs for now, as per the original description.
We still got pins left after I did #20 :)
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

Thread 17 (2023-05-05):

Replace 3.3V Regulator

tomek-szczesny, 2023-05-05:
Currently implemented LM317 requires minimum load of 2.5mA, which may drain batteries when OpenUPS is not in use.

Let's try something more modern:
https://www.mouser.pl/datasheet/2/115/DIOD_S_A0011090771_1-2543362.pdf

- Fixed 3.3V output (no external divider)
- "W5" has EN pin, which we can use to latch this regulator off when the battery is depleted (Input voltage will force it on)
- Even without EN pin, IQ is in uA range (similar to battery protector chip).

Closed 2023-05-05.

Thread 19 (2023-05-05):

Case Closure and Fasteners

hominoids, 2023-05-05:
More work is needed for better case closure due to component interference and size of the battery PCB.  Other case types are being considered e.g. snap or fitted top.  A different  thru-bolt fastener arrangement is also possible and needs to be explored more thoroughly.   The battery PCB size may also need to be increased to solve the problem.

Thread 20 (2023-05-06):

Switch to 48-pin AVR

tomek-szczesny, 2023-05-06:
We are already cornered and we don't even have LEDs yet.
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

tomek-szczesny, 2023-05-06:
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
Replaced with 48-pin TQFP.
May be easily replaced by 48-pin QFN if no traces other than GND are routed underneath TQFP (due to QFN belly pad).

Closed 2023-05-10.

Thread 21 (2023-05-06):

Preliminary MOSFET selection

tomek-szczesny, 2023-05-06:
There are many MOSFETs on a schematic, that are critical for proper operation of key components: Battery charger, voltage converters, power switches, ORing.
Some are expected to dissipate substantial heat, so mechanical requirements also apply so we can fit them under a heatsink.

NFETs:
- Vds > 30V (Some applications may require up to 24V+12V)
- Vgs (-20 : +20). Narrower range is acceptable, but schematics must be reviewed against that
- SMD, 1mm height max
- Ron < 10mR, preferrably much less than that
- Gate charge, ideally below 1uC
- Dual NFETs are welcome as most applications are half bridges

 PFETs:
- Used predominantly as ORing diodes
- Vds > 30V
- Vgs (-13 : 0) or anything beyond
- Any SMD package (no serious heat anticipated)
- Ron < 10mR or less
- Dual unit welcome

tomek-szczesny, 2023-05-14:
A preliminary NFET has been selected:
[AON7534](https://www.tme.eu/Document/be685d89ea2692b160c9c3b74c749e9a/AON7534-DTE.pdf)
Seems to fit the bill in all regards, and costs some $1 per 4 pieces (a converter usually has 4 of those).
Its DFN 3x3mm package is quite common so it will be easy to find a replacement.

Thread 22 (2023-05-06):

ESD Protection

tomek-szczesny, 2023-05-06:
Everything that is exposed outside a case must be protected against ESD, namely:
- I2C
- USB-C

The power IO is less likely to be affected due to high capacitance.

Battery PCB should also get adequate protection.

tomek-szczesny, 2023-05-16:
I2C isolator already offers ESD protection up to 8kV. No need to add anything more.
AP22814 (USB power switch) has ESD protection up to 2kV HBM.
Power outputs are not concerning, they all have substantial output capacitance (compared to 100p in Human Body Model).

USB CC lines require external ESD protection (nominal range 0-5V).
Battery TX/RX lines will require protection (nominally up to 3.3V).

Fan connector's pin 3 (Tach) requires 3.3V ESD protection.
Similarly, pin 2 needs 12V protection (may replace existing BAT54C if it's proven insufficient).

tomek-szczesny, 2023-05-22:
NUP2301MW6T1G has been applied for Bat UART lines, fan low side switches, fan tacho output and USB CC lines.

Closed 2023-05-22.

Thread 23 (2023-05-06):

Heat sink and thermal protection

tomek-szczesny, 2023-05-06:
The current baseline is reuse of Odroid C4 heatsink, also compatible with XU4 fan.
I'll need to create heatsink footprint in kicad, if we could put our hands on a reliable CAD drawing of it.

Also needed:
- Temperature sensor under a heatsink,
- XU4 fan connector, for handling the worst case scenario

tomek-szczesny, 2023-05-17:
It has been determined that XU4 fan takes too much space, so only C4 heatsink is foreseen. Thus no 5V fan controller will be implemented.

To improve thermal dissipation, internal layer 1 will be dedicated to GND. Top and bottom layers will be poured with GND as well. Turns out that heat is conducted across layers better than I anticipated.

All components must be kept under 1mm so heatsink may reach transistors and integrated converters. Care must be taken to order low profile SMD capacitors, and SOT23 components must be either placed outside the heatsink zone, or replaced with thinner counterparts.

I'm looking at you, BAT54. Fortunately these diodes are available in thinner packages (single only):
Infineon's BAT54:
BAT54-02LRH - TSLP-2-7
BAT54-02V - SC-79

Diode's BAT54LP - X1-DFN1006-2 (super small!)
ST's BAT54KFILM - SOD-523

tomek-szczesny, 2023-05-17:
Temperature sensor should be placed around the center of heatsink zone.
Preferably a I2C device (aka 2-wire or SMBus), with package under 1mm. Such as LM75BTP.147 ($.75).
Analog sensors do not offer significant cost reduction ($.6).

tomek-szczesny, 2023-05-21:
Let's not forget to add a dummy component under a heatsink if needed. XU4 has a capacitor that's sole reason is to prevent heatsink from wobbling.

tomek-szczesny, 2023-05-22:
Interesting times we're living in. Some people are actually working on a KiCad built-in heat dissipation simulator.
https://gitlab.com/kicad/code/kicad/-/merge_requests/1210

Too bad this isn't happening anytime soon. But Minions will have a responsible task in the future indeed.

tomek-szczesny, 2023-06-06:
Another note to myself, unused pins in all ICs should be connected to GND if possible, to promote better heat conduction across top layer.

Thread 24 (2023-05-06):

5th generation battery charger...

tomek-szczesny, 2023-05-06:
I can't believe that, but yeah, we're doing this, hear me out.

[BD99950](https://fscdn.rohm.com/en/products/databook/datasheet/ic/power/battery_management/bd99950muv-e.pdf). Costs about $2, and will do it all:
- Autonomously charge batteries to any voltage, and with any current desired (programmable via I2C)
- Manages switching between AC and battery supply (no ORing diodes!)
- Measures battery current (Analog output, charging only)
- Supports adapter and battery current sharing for transient high current demands (Input current is programmable)
- Learn mode, that forces one-time battery operation until a complete discharge. We could use that for a battery test mode, and calibration of whatever fuel gauge mechanism we will implement.

Yup, this will work with LiFePO4 too. Solves a few problems, but not fuel gauge.

TI seems to offer the same chip, [BQ24715](https://www.ti.com/lit/ds/symlink/bq24715.pdf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), albeit with pinout rotated by 90 degs. Hmmm...

There are more variants available, such as BQ24725A. Appears to be pin compatible as well, except its datasheet does not mention "power boost" support.

I'll implement BD chip because it's the cheapest option, and replace with TI's counterpart in case of shortage.

We've come a long way from a concept of linear charger using a single resistor, isn't it.

tomek-szczesny, 2023-05-07:
Turns out BQ24715 is not exactly the same. It is similar as far as I2C registry addresses, but a main difference is PMOS driver instead of NMOS, completely destroying any possibility of interchanging these two.

But, anyway! [BQ25731](https://www.ti.com/lit/ds/symlink/bq25731.pdf)
It is more expensive (~$4), but:
- We may get rid of the whole Vadj converter!
- Has internal ADCs, so some of the analog circuitry could be removed as well.

This charger is essentially a two-way voltage converter, that can raise or lower voltage for battery charging, as well as regulate the battery voltage back into a system bus, into a preprogrammed value. Hence, we won't need a separate converter for Vadj. This output will be simply powered from Vin (high efficiency), and supported by charger's OTG functionality when input PSU fails.

One thing I've got to confirm is a seamless transition between both states. That's the whole point of UPS. I think that's what they mean by "Fast Role Swap".

This component is slightly overcomplicated (100 pages long datasheet, half of that are I2C option listings). But if we could get rid of one voltage converter, the price of charger doesn't matter that much, so we could dig deeper for a more appropriate one.

tomek-szczesny, 2023-05-08:
BQ25731 datasheet, I read this thing. It says very little about its Fast Role Swap feature - just that it's compliant with USB specs, and factory should be contacted for more details. Cryptic.

I did some reading on Fast Role Swap elsewhere. Seems like it allows for the input voltage to drop down to 5V for some undefined period. This is because USB-powered devices generally should still work at 5V. Not what we're after.

Here's what I'm ultimately trying to achieve:
1. Either a switching battery charger that can lower the voltage for battery charging, and boost it up back on discharge, and do it seamlessly. I can see why this might not exist at all: Inductor's "current momentum" that opposes current flow reversal. Not to mention, I fail to see a real world application for this 🤣  If that was possible, however, his approach would allow us to get rid of Vadj converter entirely.
2. OR, a simpler battery charger that also switches between power input and battery, regardless of output ("system") voltage.

I was hoping that BQ25731 is an example of category 1, but I can't find sufficient evidence that it can do what we are after, with no interruptions. If there was any chip like that, costing less that some $8, would still be worth it.

BD99950 appears to be a category 2 chip, except its datasheet doesn't explicitly say so, nor TI's counterpart's. Also this chip will have no power when AC is gone. So, how will it keep the battery MOSFET on? Some small details hints that the charge pump might be powered by the battery itself. One sentence underlines that both charge pumps are independent. Electrical characteristics list battery standby current when AC is not detected. The block diagram shows this charge pump connected to BATT pin, with no explanation.

BQ24715, which is almost exactly the same, differs in one detail, which is battery control MOSFET - they used PFET instead. And they did mention that it's pulled to ground by 50k resistor. So when this chip loses power, the battery should remain connected.

ROHM's BD chip appears to be released 2 years after BQ, so I suppose they bought the design and improved it. NMOS is an improvement indeed, if it works like I hope it does.

So, to wrap it up, I guess I'll carry on implementing BD99950, with two extra steps just in case:
- An extra diode for keeping this chip powered on when AC is gone
- A placeholder for a parallel ideal diode, in case this chip is dumber than I thought.

Let's not forget that with 12V power input, we won't be able to charge the batteries up to 12.6V, but I guess it's been assumed for the long time now that 12V will cover most of their charge anyway. Not a problem with LiFePO4 though.

Closed 2023-05-10.

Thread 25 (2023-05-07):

The Wiki

tomek-szczesny, 2023-05-07:
As for now in the development stage I take the opportunity to dump functional and implementation bits and bobs, especially for the contributors.

Ideally, we would like to maintain the project Wiki in useful state after the project is done.
Of course the user's manual will go there, as well as technical description with varying degree of detail.
I prefer having incomplete but correct source of information, if I had to choose between the two. That's why I intend to maintain it as we progress, at the very least by removing outdated information.

Everyone is welcome to contribute to Wiki, especially because writing extensive documentation in a foreign language is a time consuming process for me.

Unfortunately Wiki is a repository that - as far as I know - cannot be branched. So in case anyone wishes to contribute, let me know here and we'll figure out a way to make this work.

Here's a structure I have in mind:
1. Introduction. What is this project about, feature list etc
2. User's Manual
3. Design Description (System level)
4. Detailed Design Description
-- Linux Host Software
-- UPS PCB
-- AVR Firmware for UPS PCB
-- BAT PCB
-- BAT Firmware
-- Case?
5. Implementation details (not exhaustive, only stuff we wrote down for any reason)

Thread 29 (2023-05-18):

Buck Boost layout (NCP81599)

tomek-szczesny, 2023-05-18:
The datasheet doesn't say much about a recommended layout, other than 1 page of generic advice, "place everything as close as possible".
The reference design manual has a photo of their EVB: https://www.onsemi.com/download/eval-board-manual/pdf/ncp81599gevb_user_guide.pdf
Clearly they did not care much about distances, and yet it works.

The layout gets complicated, because two such converters must fit next to each other, with active components under the heatsink, and inductor (as well as decoupling caps) must stay outside.

5V converter may need to be moved elsewhere to meet those demands.

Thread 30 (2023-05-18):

Add USB power output override

tomek-szczesny, 2023-05-18:
Current USB-C application sources 5V 3A only when CC pins are being driven accordingly by downstream device.
Additional transistor should be implemented to force USB output on, in order to support non-compliant devices.
This will be an advanced option operated by PC software.

tomek-szczesny, 2023-05-22:
It's off by default until the microcontroller drives this pin high.

Closed 2023-05-22.

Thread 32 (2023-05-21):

Non-technical content on PCB silkscreen

tomek-szczesny, 2023-05-21:
Even zyssai's board has a nice logo on it, perhaps we could come up with something of our own?
That is, if we cling to that OpenUPS branding. So far google searches of OpenUPS return some other product...

And of course the open source hardware symbol should land on the board (bottom side, probably).
The bottom side will be mostly empty, so we can put almost anything on it.

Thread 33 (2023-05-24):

Additional mount hole

tomek-szczesny, 2023-05-24:
A fifth hole is to be added somewhere near the connector-filled edge, around the center.
At the same time, some of the existing holes may be moved for better THT cap placement.

tomek-szczesny, 2023-05-24:
@hominoids, I moved one hole 2mm "up", in order to make room for bottom side capacitors.
No need to update models on your side until I add the fifth hole (not today).

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

hominoids, 2023-05-25:
My plan right now is to wait until your done with the layout before updating the model and drawings.  Make whatever changes you need.

tomek-szczesny, 2023-05-25:
Exactly what I had in mind, I'll carry on accumulating my changes here then.

tomek-szczesny, 2023-05-25:
South east hole moved 3mm down.
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

tomek-szczesny, 2023-05-28:
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
@hominoids , the fifth hole has landed. Please update your mechanical design. :)

hominoids, 2023-05-29:
I made the changes to date and added an option in the GUI to show the KiCAD Model for alignment verification.  For now it's kept in ./case/lib and can be updated by replacement.

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

tomek-szczesny, 2023-05-29:
Looks like spray painted. ;)
I'm glad the alignment isn't broken yet. Quality documentation paid off.

Let's keep this issue open for future mechanical changes, if any.

hominoids, 2023-06-04:
I was able to increase the UPS PCB from 90x62mm to 96x64mm.  Take notice of the area directly over the drive bay nut holder that has been trimmed away for PCB clearance, no components there.  I also superimposed the old KiCad model to show how the holes have been moved.

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

The forward UPS mount holes cannot be moved any further outward because of the narrower battery PCB.  And, the rear battery PCB holes/standoffs have been moved forward 2mm more to accommodate the extra depth of the UPS PCB.  I'm still working to see if a dual 3S1P case is possible.

DXF Drawing of the new enlarged PCB and holes.

[OpenUPS_PCB_Changes.dxf.zip](https://github.com/tomek-szczesny/OpenUPS/files/11644619/OpenUPS_PCB_Changes.dxf.zip)

hominoids, 2023-06-04:
I added the keep out areas and also made other adjustments so don't use the previous version for anything.  The keep out area for the bottom inward facing XT30 is not in the correct location and needs to be repositioned since it has moved. There is extra room around the rear I2C that could be used for another connector if needed.  It could face inward and serve the battery PCB on another bus or the area could be used to replace one of the JST-SH(1mm) with a JST-PH(2mm) for a cabling choice.

[OpenUPS_PCB_Changes_Updated.dxf.zip](https://github.com/tomek-szczesny/OpenUPS/files/11646375/OpenUPS_PCB_Changes_Updated.dxf.zip)

tomek-szczesny, 2023-06-06:
@hominoids we could use the extra space on a back facing edge to move fan ports apart, so both could support 4-pin connectors. Could you estimate how far away from each other they should be? I assume it's about 10mm and some.

tomek-szczesny, 2023-06-06:
How wide is the inter-PCB overlap? I'll add a keep out zone there as well, as it's been tempting to place capacitors in there.

hominoids, 2023-06-06:
The 4-pin fan connector is 10.5mm wide and the 3-pin measures 8.17mm.  Here is a photo of both so the positioning relative to the friction clip and wiring is clear.

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

There is a 10mm overlap between the PCB. Note, currently only the east side has components on the battery PCB so I've added a 10mm x 33mm keep out zone only in that area.

[OpenUPS_PCB_Overlap.dxf.zip](https://github.com/tomek-szczesny/OpenUPS/files/11668029/OpenUPS_PCB_Overlap.dxf.zip)

tomek-szczesny, 2023-06-14:
I've done some sokoban exercises, spreaded out FAN and Qwiic connectors. Those changes will be available in the following commit. Are you able to extract component coordinates on your own?

FAN connectors are 11mm apart (measured between their centers), so two 4-pin fans should be supported now.

Also by squishing the components in there I made more room for the charger.

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

The same commit will include this preliminary placement of 6-pin JSTs, sharing common pin holes, and XT30 which more or less remained in the same spot.

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

I'm sorry for the long delay, I'm still recovering from an unpleasant illness.

hominoids, 2023-06-15:
Sounds good, I hope you feel better soon.

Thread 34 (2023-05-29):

New approach to battery supervision

tomek-szczesny, 2023-05-29:
Investigating a new idea of removing (or significantly reducing) battery supervision microcontroller.

The foreseen benefits include single, centralized firmware on UPS AVR, and removing need for support of a middleman in communication. Also, users will not have to push the button on the battery pack PCB to boot it after assembly. And finally, disconnected battery will actually enter a long term storage mode, and will only work with data link connected.

This is how I see it as of today:
- Internal I2C bus present on UPS PCB gets extended to 2-pin data connector of the battery,
- UPS PCB's AVR can talk to BQ769x0 directly via I2C, and only I2C
- BAT PCB has a mechanism that puts BQ chip into SHIP mode if no I2C activity is detected.

To me it sounds foolproof. It also serves as a protection against AVR failure, a measure unforeseen until now.

SHIP mode may be activated by either sending a special I2C sequence, or forcing the BQ chip to go through POR (Power On Reset). The latter is discouraged by the datasheet.
At the same time, a mechanism that transitions BQ chip from SHIP to NORMAL mode is required. This is achieved by pulling a temperature sensor pin TS1 above 1V threshold for at least 2ms.

The BAT PCB implementation could be a minimal AVR with I2C port and one more GPIO. Attiny 212/412 fits the bill.
During normal operation, it would passively watch SCK and SCL, possibly with its internal TWI peripheral disabled. If it detects no activity (SCK idle for > 1000ms), it will turn on its I2C Master interface and order BQ to go into SHIP mode. AVR will then lose its power source, as I assume BQ's external LDO will be shut down as well (I can't find confirmation for this). If not, AVR will implement sleep mode.

When BAT PCB gets connected to UPS PCB, either AVR will get temporarily powered from the I2C lines, or it will wake up triggered by SCK pulled high. Both of these may be implemented concurrently. It will then wake up BQ chip by pulling its TS1 pin high. From this point AVR will be powered entirely from BQ's LDO.

Alternatively, BQ wake up may be implemented as a I2C command that battery side AVR will detect and execute on demand.

Finally, the battery side AVR may support up to 3 configuration jumpers for user configuration of battery chemistry type. Those may be readable via I2C. One of these pins may be used for programming said AVR via UPDI.

Am I missing anything?

hominoids, 2023-05-29:
A diagram... :)
I made some system diagrams to document and better understand the implementation.  The first is the original approach and the second is the new proposed approach.  Where should we permanently store this information?  What needs to be done to add it to the wiki?   I used drawio available [here](https://github.com/jgraph/drawio-desktop/releases/tag/v21.2.8) if you want to directly change either.
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
Source file: [OpenUPS_Diagram-v0.90.drawio.zip](https://github.com/tomek-szczesny/OpenUPS/files/11592459/OpenUPS_Diagram-v0.90.drawio.zip)

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
Source file: [OpenUPS_Diagram-v0.91.drawio.zip](https://github.com/tomek-szczesny/OpenUPS/files/11592465/OpenUPS_Diagram-v0.91.drawio.zip)

tomek-szczesny, 2023-05-29:
I was reluctant to work on a diagram because I haven't found any tool that beats pencil and paper, but I think I can work with that. :)

I'll expand the second diagram today - everything seems correct except one small detail, but also there are a few things missing.

Feel free to add anything you like to the wiki. It is accessible as a separate repository:
[git@github.com:tomek-szczesny/OpenUPS.wiki.git](git@github.com:tomek-szczesny/OpenUPS.wiki.git)
I'm not sure whether we can keep diagram in this repo, but that would be really helpful.

I recommend markdown editor, [marktext](https://github.com/marktext/marktext/releases/tag/v0.17.1). It explicitly supports github specific syntax if selected somewhere in the settings.

tomek-szczesny, 2023-05-29:
I don't think I instantly fell in love with this tool. Certainly better than many others I've seen before, but I'll have to invest some time learning it. Most notably, it doesn't seem to support branching arrows, which would be super useful to us.

I identified a reason for using a separate TWI for a battery - the BQ chip's I2C works at 100kHz, in contrast to usual 400kHz. We don't want to cap the whole bus like that. Also less traffic will improve latency on this critical bus.

There are still plenty of signals missing (mostly housekeeping metrics), but this is a good start for implementing necessary modules.

But to stay on topic, do you like the proposed battery handling solution?

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
[OpenUPS_Diagram-v0.92.drawio.zip](https://github.com/tomek-szczesny/OpenUPS/files/11593236/OpenUPS_Diagram-v0.92.drawio.zip)

hominoids, 2023-05-29:
I just started using drawio too and didn't take the time to find away to do branching arrows.  But I agree, it's better then most I have used.

The diagram looks good and is the best solution to date imo.  For discussion, there is a way to solve all the startup, safety, cable connection issues and also reduce the component count and cost significantly.  The BQ76200, ATtiny and all supporting components could be eliminated by simply moving the BQ76920 onto the UPS PCB.  By using the +Batt, -Batt and the balance/sense lines in a JST connector, the BQ76920 would know on startup or immediately while operating, if the battery pack or balance/sense lines were not attached and it would also know if someone removed any single battery.   The internal low-side FET of the BQ76920 could be used and the BQ76200 wouldn't be needed.

For all of the above reason and maybe more, I suspect this is why most uses of multiple or different size packs use this method, it's safe.  It's very typical in some use categories for a battery pack to have power leads and a JST connector for the balance/sense lines.  It deserves some consideration and actually opens up supporting other battery packs, easily making your own and automatic battery configuration could be possible and be implemented in SW.  Just some things to thing about.  The UPS PCB could be widened back to 94mm adding 4mm more but I don't know if we could get any more depth, maybe 1mm-3mm at best but I would need to look.

tomek-szczesny, 2023-05-29:
I really do like this idea, with 8-pin JST cable this would work like you say, in nominal conditions. But I fear that won't solve all of the problems we've faced so far.

BQ76200 has been introduced because I saw no reasonable way of passing UART (or I2C) over the broken GND connection. This problem would still be there, unfortunately, and having it all on a single PCB won't get us any closer to a solution.
High side switch would also be necessary to keep BQ76920 properly grounded at all times, otherwise it may disrupt the I2C operation when the battery is not present (pulling I2C lines up to charger's positive voltage, if not burning in the process).

So, I guess this could work, with JST cable with at least 7 leads (6 for the cells, extra one for temperature sensor), but unfortunately with my current knowledge we're only saving attiny212.

We could however toy with an idea of replacing BQ76200 and high-side mosfets with a single-chip eFuse / hot swap solution.
Such as [TPS25981](https://www.ti.com/lit/ds/symlink/tps25981.pdf). Except it's ridiculously small, but at least protects well against shorts and discharge overcurrent. No protection against charge current though.

tomek-szczesny, 2023-05-30:
Honestly I'm not convinced. That's a lot of effort to squeeze in all the battery related circuits into UPS mainboard. It may look empty now but most of that empty space is already dedicated to MOSFET cooling copper pours.
A much bigger JST connector will not make matters easier, not to mention rather unusual cable.

And I'm really worried how will BQ76920 react to battery voltage and sense signals appearing separately, in unspecified order. With high side switch that may be a minor issue, probably requiring clearing some error flags.

In my opinion, this idea is worth further consideration only if we come up with a significant cost reduction of a battery related chipset. The most significant advantage of this approach is that the complexity of connections between battery support circuits and AVR is now unlimited.
I searched for a while, but it's unlikely we'll find a coulomb counter, battery monitor, balancer, and protection for a lower price.

For example, [BQ76925](https://www.ti.com/lit/ds/symlink/bq76925.pdf) is about half the price of BQ76920 but the main tradeoff is that it uses microcontroller's ADC. That can be arranged, AVR DB has "up to 22" ADC inputs. The aforementioned efuse is half the price of BQ76200 and associated FETs. I was unable to find a coulomb counter for multi-cell batteries that would not bring all these savings down to null.

There is also this affordable chip with everything we need. Too much in fact, also comes with 200 pages long programming manual and has an on-board CPU. The [BQ4050](https://www.ti.com/lit/ds/symlink/bq4050.pdf).

You did mention that you are familiar with at least one instance of a battery management circuits separate from the battery pack - perhaps we could get some inspiration from them? Is there any open source project that does that?

tomek-szczesny, 2023-05-30:
L9961 has lost its appeal once I dug into its datasheet and realized the register map is nowhere to be found. HK had unpleasant experience with ST while developing SmartPower3 - they simply do not respond. So I won't even bother asking them for a missing piece of documentation, I suspect they withheld it for a reason.
Pity, it's a very cheap chip that does everything we wanted.

OK I did take a look on LibreSolar. Indeed, they are doing what you said they would, battery nanny on a separate board from the batteries.
The chips they support are super expensive, except our old pal BQ76920 and somewhat acceptable BQ76952.

It does everything we want. It is such a waste to employ a 15S capable chip in OpenUPS. There is a counterpart that works with only 10S packs, BQ76942, albeit the package is the same and price differs by mere 10%.
And you could benefit from the existing open source software, I reckon. This appears to be the most reasonable solution for now, but I'll have to take a closer look at this chip tomorrow.

It also came to my attention that we could use one of its three temperature monitoring channels to monitor UPS PCB temperature, instead of adding a separate I2C device for this purpose. Hooray, another dollar saved.

tomek-szczesny, 2023-06-02:
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
[OpenUPS_Diagram-v0.93.drawio.zip](https://github.com/tomek-szczesny/OpenUPS/files/11635262/OpenUPS_Diagram-v0.93.drawio.zip)

A slightly updated diagram with my freshest idea for dealing with battery pack.

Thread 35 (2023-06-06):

AVR in VQFN package

tomek-szczesny, 2023-06-06:
AVR will most likely end up under the heatsink, so we'll need a slim package for it.

The standard kicad footprint has some 6000 heat sinking vias on the central pad, so maybe we'll require a custom footprint with a reasonable amount, like one or five. AVR is not expected to heat up in a meaningful way.

Closed 2023-06-08.

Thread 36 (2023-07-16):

SPI Interface Access

hominoids, 2023-07-16:
Access to SPI would be beneficial for the use of an LCD display during firmware development and as an additional UPS feature.  It could be used to enhance a standalone case or as a remote display in an integrated server case.  No SPI interfaces are currently used so a single header could provide the needed interface if board space and layout allows.

In further research there isn’t any clear SPI connector standards that are widely adapted.  The ones that are currently used are from specific makers tied to their products.

• PMOD, a standard by Digilent with 0.1” pin headers, for SPI channels, a 1x6 connector with pin order {SS, MOSI, MISO, SCK, GND, Vcc}

• EYESPY  a standard by Adafruit for displays using SPI that also supports I2C for touch screens, using a 0.5 pitch 18 pin FPC connector with pin order {Vcc,LITE,GND,SCK,MOSI,MISO,TFTDC,TFTRST,TFTCS,CARDCS,MEM_CS,TSCS,SCL,SDA,INT,BUSY,GPIO1,GPIO2}

• Beaglebone Blue, 1 mm pitch JST-SH connectors used for SPI channels, a 6-pin connector with pin order {GND, 3.3V, MOSI, MISO, SCK, SS}

The EYESPY is the most interesting because of it’s increased capability and adaptability to different displays.  Not all signals have to be used as demonstrated in the [breakout board example](https://learn.adafruit.com/adafruit-eyespi-breakout-board).  By including I2C and the  other CS signals in the FPC cable, a [touchscreen display](https://www.adafruit.com/product/2090) is now possible.  The schematic and pin order can be found at the downloads page.

If PCB space was unlimited, the ideal situation would be to deploy a full EYESPY FPC connector but also have a 6 pin 2.54mm header for extra flexibility for non compliant LCD displays.  Regardless of how far one wants to take this, it seems to me that for the price of a pin header, at least one SPI 6-pin 2.54mm header is justified for basic display capability.

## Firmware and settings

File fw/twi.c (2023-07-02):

/*
 * Copyright (c) 2023 Edward Kisiel hominoid@cablemi.com All rights reserved.
 *
 * FILE:        twi.c
 * LICENSE:     GNU GPLv3
 * DESCRIPTION: AVRDx TWI driver for I2C and SMBUS interface.
 *
*/
 
#include <stdint.h>
#include <stddef.h>
#include <stdbool.h>
#include <util/delay.h>
#include <avr/io.h>
#include <avr/interrupt.h>
#include "twi.h"

/* 
 *  DESCRIPTION: twi initialization for all ports and modes.
 *   
 *         NAME: uint8_t twi_init(uint8_t TWIPORT, uint8_t TWI_MODE, uint8_t FREQ, struct twi_bus *twi_bus)
 
 *   PARAMETERS: TWIPORT = TWI0_PORT, TWI1_PORT
 *               TWI_MODE = TWI_MODE_HOST, TWI_MODE_CLIENT, TWI_MODE_DUAL
 *               FREQ = 100000, 400000, 1000000
 *               *twi_bus = struct twi_bus {
 *                  int  bustype;     TWI_I2C, TWI_SMB
 *                  int  pins;        TWI_PINS_DEFAULT, TWI_PINS_ALT1, TWI_PINS_ALT2
 *                  int  sdahold;     TWI_SDAHOLD_OFF_gc, TWI_SDAHOLD_50NS_gc, 
 *                                      TWI_SDAHOLD_300NS_gc, TWI_SDAHOLD_500NS_gc
 *                  int  sdasetup;    TWI_SDASETUP_4CYC_gc, TWI_SDASETUP_8CYC_gc
 *                  int  timeout;     TWI_TIMEOUT_DISABLED_gc, TWI_TIMEOUT_50US_gc
 *                                      TWI_TIMEOUT_100US_gc, TWI_TIMEOUT_200US_gc 
 *                  bool pullup;      true, false
 *                  bool smart;       true, false
 *                  bool intrupt;     true, false
 *
 *       RETURN: SUCCESS = 0, FAIL = -1
 *
 *         TODO: WIP
 *
 */
 
uint8_t twi_init(uint8_t TWIPORT, uint8_t TWI_MODE, uint32_t FREQ, struct twi_bus *twi_bus) {

    if(TWIPORT == TWI0_PORT) {   
        // set twi pin mux
        switch(twi_bus->pins) {
            case TWI_PINS_ALT1 :
                PORTMUX_TWIROUTEA = PORTMUX_TWI0_ALT1_gc;   /* PA2, PA3, PC6, PC7 */
                PORTA_DIRSET = PIN2_bm | PIN3_bm;
                if(twi_bus->pullup == true) PORTA_PINCONFIG = PORT_PULLUPEN_bm;
                PORTA_PINCTRLUPD = PIN2_bm | PIN3_bm;
            case TWI_PINS_ALT2 :
                PORTMUX_TWIROUTEA = PORTMUX_TWI0_ALT2_gc;   /* PC2, PC3, PC6, PC7 */
                PORTC_DIRSET = PIN2_bm | PIN3_bm;
                if(twi_bus->pullup == true) PORTC_PINCONFIG = PORT_PULLUPEN_bm;
                PORTC_PINCTRLUPD = PIN2_bm | PIN3_bm;
            case TWI_PINS_DEFAULT :
                PORTMUX_TWIROUTEA = PORTMUX_TWI0_DEFAULT_gc;    /* PA2, PA3, PC2, PC3 */
                PORTA_DIRSET = PIN2_bm | PIN3_bm;
                if(twi_bus->pullup == true) PORTA_PINCONFIG = PORT_PULLUPEN_bm;
                PORTA_PINCTRLUPD = PIN2_bm | PIN3_bm;
                PORTA_OUT = (0 << PIN2_bp) & (0 << PIN3_bp);
            default :
                break;
        }

        if(TWI_MODE != TWI_MODE_DUAL) {
            // configure INPUTLVL
            switch(twi_bus->bustype) {
                case TWI_I2C :
                    TWI0_CTRLA = TWI_INPUTLVL_I2C_gc;
                case TWI_SMB :
                    TWI0_CTRLA = TWI_INPUTLVL_SMBUS_gc;
                default :
                    break;
            }

        }

        // configure SDAHOLD 
        switch(twi_bus->sdahold) {
            case TWI_SDAHOLD_OFF_gc :
                TWI0_CTRLA = TWI_SDAHOLD_OFF_gc;
            case TWI_SDAHOLD_50NS_gc :
                TWI0_CTRLA = TWI_SDAHOLD_50NS_gc;
            case TWI_SDAHOLD_300NS_gc :
                TWI0_CTRLA = TWI_SDAHOLD_300NS_gc;
            case TWI_SDAHOLD_500NS_gc :
                TWI0_CTRLA = TWI_SDAHOLD_500NS_gc;
            default :
                break;
        }
        
        if(TWI_MODE == TWI_MODE_HOST) {               
            // enable smart mode
            if(twi_bus->smart) TWI0_MCTRLA = TWI_SMEN_bm;          
            
            // set SM, FM or FM+ based on FREQ
            if(FREQ == 1000000UL) {
                TWI0_CTRLA = TWI_FMPEN_ON_gc;
            }
            else {
                TWI0_CTRLA = TWI_FMPEN_OFF_gc;
            }

            // set FREQ rate
            TWI0_MBAUD = TWI0_BAUDRATE(FREQ, 350);
            
            // configure TIMEOUT
            switch(twi_bus->timeout) {
                case TWI_TIMEOUT_DISABLED_gc :
                    TWI0_CTRLA = TWI_TIMEOUT_DISABLED_gc;
                case TWI_TIMEOUT_50US_gc :
                    TWI0_CTRLA = TWI_TIMEOUT_50US_gc;
                case TWI_TIMEOUT_100US_gc :
                    TWI0_CTRLA = TWI_TIMEOUT_100US_gc;
                case TWI_TIMEOUT_200US_gc :
                    TWI0_CTRLA = TWI_TIMEOUT_200US_gc;
                default :
                    break;
            }
            
            // set bits for read and write interupts
            if(twi_bus->intrupt) TWI0_MCTRLA = TWI_WIEN_bm | TWI_RIEN_bm;
 
            // set ENABLE bit
            TWI0_MCTRLA = TWI_ENABLE_bm;

            // clear MSTATUS and set BUSSTATE to force idle
            TWI0_MSTATUS = TWI_RIF_bm | TWI_WIF_bm | TWI_CLKHOLD_bm | TWI_RXACK_bm |
                TWI_ARBLOST_bm | TWI_BUSERR_bm | TWI_BUSSTATE_IDLE_gc;
            
            // check for idle state
            if(TWI0_MSTATUS & TWI_BUSSTATE_1_bm == 1) {
                return(SUCCESS);
            }
            else {
                return(FAIL);
            }
        }
        
        if(TWI_MODE == TWI_MODE_CLIENT) {

            // enable smart mode
            if(twi_bus->smart) TWI0_SCTRLA = TWI_SMEN_bm;
                
            // configure SDASETUP
            switch(twi_bus->sdasetup) {
                case TWI_SDASETUP_4CYC_gc :
                    TWI0_CTRLA = TWI_SDASETUP_4CYC_gc;
                case TWI_SDASETUP_8CYC_gc :
                    TWI0_CTRLA = TWI_SDASETUP_8CYC_gc;
                default :
                    break;
            }
            
            // set bits for address, stop and data interupts
            if(twi_bus->intrupt) TWI0_SCTRLA = TWI_APIEN_bm | TWI_DIEN_bm | TWI_PIEN_bm;

            // set address
            TWI0_SADDR = TWI0_ADDR << 1;
            
            // set ENABLE bit
            TWI0_SCTRLA = TWI_ENABLE_bm;
            
            return(SUCCESS);
        }
        
        if(TWI_MODE == TWI_MODE_DUAL) {
            // configure INPUTLVL
            switch(twi_bus->bustype) {
                case TWI_I2C :
                    TWI0_DUALCTRL = TWI_INPUTLVL_I2C_gc;
                case TWI_SMB :
                    TWI0_DUALCTRL = TWI_INPUTLVL_SMBUS_gc;
                default :
                    break;
            }

            // configure SDASETUP
            switch(twi_bus->sdasetup) {
                case TWI_SDASETUP_4CYC_gc :
                    TWI0_DUALCTRL = TWI_SDASETUP_4CYC_gc;
                case TWI_SDASETUP_8CYC_gc :
                    TWI0_DUALCTRL = TWI_SDASETUP_8CYC_gc;
                default :
                    break;
            }
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

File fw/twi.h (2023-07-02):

/*
 * Copyright (c) 2023 Edward Kisiel hominoid@cablemi.com All rights reserved.
 *
 * FILE:        twi.h
 * LICENSE:     GNU GPLv3
 * DESCRIPTION: AVRDx TWI driver for I2C and SMBUS interface.
 *
*/

#define SUCCESS                             0
#define FAIL                                -1

#define F_CPU                               4000000UL
#define CLK_PER                             4000000UL

#define TWI_WRITE                           0
#define TWI_READ                            1

/* TWI PINS */
#define TWI_PINS_DEFAULT                    0
#define TWI_PINS_ALT1                       1
#define TWI_PINS_ALT2                       2
 
/* TWI0 setttings */
#define TWI0_PORT                           0
#define TWI0_ADDR                           0x18
#define TWI0_BAUD                           100000
#define TWI0_BAUDRATE(F_SCL, T_RISE)        ((((((float)CLK_PER / (float)F_SCL)) - 10 - ((float)CLK_PER * T_RISE))) / 2)

//#define TWI0_BAUDRATE(F_SCL, T_RISE)        ((F_CPU / TWI0_BAUD) / 2) - (5 + (((F_CPU / 1000000) * T_RISE) / 2000))

/* TWI1 setttings */
#define TWI1_PORT                           1
#define TWI1_ADDR                           0x68
#define TWI1_BAUD                           100000
#define TWI1_BAUDRATE(F_SCL, T_RISE)        ((((((float)CLK_PER / (float)F_SCL)) - 10 - ((float)CLK_PER * T_RISE))) / 2)

#define TWI_MODE_HOST                       0
#define TWI_MODE_CLIENT                     1
#define TWI_MODE_DUAL                       2
#define TWI_READ_ACK                        1
#define TWI_READ_NACK                       0

/* error messages */
#define TWI_ERROR_NOHOST                   -2
#define TWI_ERROR_START                    -3
#define TWI_ERROR_ADDR                     -3
#define TWI_ERROR_NACK                     -4
#define TWI_ERROR_READ                     -5
#define TWI_ERROR_WRITE                    -6
#define TWI_ERROR_REGREAD                  -7

#define TWI_I2C                             0
#define TWI_SMB                             1

enum {
    TWI_INIT = 0, 
    TWI_ACKED,
    TWI_NACKED,
    TWI_READY,
    TWI_ERROR
};

struct twi_bus {
    int  bustype;    // TWI_I2C, TWI_SMB
    int  pins;       // TWI_PINS_DEFAULT, TWI_PINS_ALT1, TWI_PINS_ALT2
    int  sdahold;    // TWI_SDAHOLD_OFF_gc, TWI_SDAHOLD_50NS_gc, TWI_SDAHOLD_300NS_gc, TWI_SDAHOLD_500NS_gc
    int  sdasetup;   // TWI_SDASETUP_4CYC_gc, TWI_SDASETUP_8CYC_gc
    int  timeout;    // TWI_TIMEOUT_DISABLED_gc, TWI_TIMEOUT_50US_gc, TWI_TIMEOUT_100US_gc, TWI_TIMEOUT_200US_gc 
    bool pullup;     // true, false
    bool smart;      // true, false
    bool intrupt;    // true, false
};

uint8_t twi_init(uint8_t TWIPORT, uint8_t TWI_MODE, uint32_t BAUD, struct twi_bus *twi_bus);
uint8_t twi_start(uint8_t TWIPORT, uint8_t TWIADDR, uint8_t TWICMD);
uint8_t isTWI_valid(uint8_t TWI_PORT);
uint8_t twi_wait(uint8_t TWI_PORT, uint8_t mode);
uint8_t twi_read_poll(uint8_t TWIPORT, volatile uint8_t *data, uint8_t len);
uint8_t twi_write_poll(uint8_t TWIPORT, volatile uint8_t *data, uint8_t len);
uint8_t twi_read_reg(uint8_t TWIPORT, uint8_t TWIADDR, uint8_t reg_addr, volatile uint8_t *data, uint8_t len);
uint8_t twi_read(uint8_t TWIADDR, volatile uint8_t* data, uint8_t len);

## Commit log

2023-04-21 Initial KiCAD commits
    [12V_Buck.kicad_sch, 12V_Buck_Boost.kicad_sch, 5V_Buck.kicad_sch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]
2023-04-21 More cleanups and stuff
    [12V_Buck.kicad_sch, 12V_Buck_Boost.kicad_sch, 5V_Buck.kicad_sch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]
2023-04-22 Fixed ground symbols
    [OpenUPS_bat.kicad_sch]
2023-04-22 Preliminary battery charger circuit
    [Bat_Charger.kicad_sch, OpenUPS_ups.kicad_sch]
2023-04-22 initial commit of PCB models, updated readme.md
    [OpenUPS_Case.scad]
2023-04-23 added drivebay case
    [OpenUPS_Case.scad]
2023-04-23 created terminal block screw openings and annotation
    [OpenUPS_Case.scad]
2023-04-23 Secondary blocks design
    [Bat_Charger.kicad_sch, Molex_-_22-05-3031.step, OpenUPS_ups.kicad_sch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]
2023-04-23 code cleanup and xt60 creation
    [OpenUPS_Case.scad]
2023-04-24 mini case work
    [OpenUPS_Case.scad]
2023-04-24 more mini case refinement
    [OpenUPS_Case.scad]
2023-04-24 updated image
    [OpenUPS_Case.scad]
2023-04-24 Added Ideal Diode ORing solution
    [OpenUPS_ups.kicad_sch, oring.kicad_sch]
2023-04-24 Change minimum input voltage back to 12V
2023-04-25 Upgraded battery charger with synchronous HB Driver
    [Bat_Charger.kicad_sch, OpenUPS_ups.kicad_sch, aux.kicad_sch]
2023-04-26 Battery charger HB driver changed to NCP5901
    [Bat_Charger.kicad_sch, OpenUPS_ups.kicad_sch, aux.kicad_sch]
2023-04-28 platter view created, swapped i2c and fan, more code cleanup
    [OpenUPS_Case.scad]
2023-04-28 created xt30 components and changed mini case to use xt30
    [OpenUPS_Case.scad]
2023-04-28 work on 3s1p battery case
    [OpenUPS_Case.scad]
2023-04-28 work on 3s2p battery case
    [OpenUPS_Case.scad]
2023-04-30 4th generation battery charger
    [Bat_Charger.kicad_sch, OpenUPS_ups.kicad_sch]
2023-05-01 increased space for fan connectors
    [OpenUPS_Case.scad]
2023-05-01 External I2C isolator
    [Bat_Charger.kicad_sch, OpenUPS_ups.kicad_sch, ext_i2c.kicad_sch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]
2023-05-02 customizer gui added
    [OpenUPS_Case.scad]
2023-05-02 corrected staggered battery clip placement
    [OpenUPS_Case.scad]
2023-05-02 Work on Buck Boosts
    [12V_Buck_Boost.kicad_sch, OpenUPS_ups.kicad_sch, aux.kicad_sch]
2023-05-02 Work on 5V; EN pins taken care of.
    [12V_Buck_Boost.kicad_sch, 5V_Buck.kicad_sch, Bat_Charger.kicad_sch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]
2023-05-03 Added ports and fuses
    [691213710002 (rev1).stp, OpenUPS_ups.kicad_sch, fans.kicad_sch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]
2023-05-05 Issue #17
    [OpenUPS_ups.kicad_sch, aux.kicad_sch]
2023-05-05 Issue #13, USB-C output, at last!
    [OpenUPS_ups.kicad_sch, usbc.kicad_sch]
2023-05-06 Issue #20: replaced AVR with 48-pin TQFP
    [OpenUPS_ups.kicad_sch]
2023-05-06 Issue #16: Added LED indicators
    [OpenUPS_ups.kicad_sch, leds.kicad_sch]
2023-05-07 increased 3s1p battery pcb size, adjusted drivebay case
    [OpenUPS_Case.scad]
2023-05-08 more work for battery pcb size increase and case pillars.
    [OpenUPS_Case.scad]
2023-05-09 Issue #24 5th generation charger (may need some tuning)
    [Bat_Charger.kicad_sch, OpenUPS_ups.kicad_sch, prog.kicad_sch]
2023-05-10 xt30 orientation change and additional foot prints for all pcb, added 3s1p pcb dxf drawing, updated image
    [3S1P_Battery_PCB.dxf, OpenUPS_Case.scad]
2023-05-10 Issue #24 - battery charger, good for review
    [Bat_Charger.kicad_sch, OpenUPS_ups.kicad_sch]
2023-05-12 added header interconnect, arranged battery connctors, led, usb-c and other changes
    [OpenUPS_Case.scad]
2023-05-12 created dxf file for ups and 3s2p pcb, updated openups_pcb.png
    [3S2P_Battery_PCB.dxf, OpenUPS_Case.scad, OpenUPS_PCB.dxf]
2023-05-13 Revert "work on 3s2p battery case"
    This reverts commit d35319efd431c702fc1be0438e49ec9e5fffffa4.
    [OpenUPS_Case.scad]
2023-05-13 Revert "work on 3s1p battery case"
    This reverts commit 1a45b3675fc5b00893d7b6622b8964d1ce6814fb.
    [OpenUPS_Case.scad]
2023-05-13 Revert "created xt30 components and changed mini case to use xt30"
    This reverts commit ccc60c90d4db5fe0236a61b43db1235a52bc742a.
    [OpenUPS_Case.scad]
2023-05-13 Revert "platter view created, swapped i2c and fan, more code cleanup"
    This reverts commit 2f2f817d291441a83b86ed38aa68c17b6ac24d99.
    [OpenUPS_Case.scad]
2023-05-13 Revert "Change minimum input voltage back to 12V"
    This reverts commit 13d1a0fb0a5e56c0f9c625028acc5f1636d0e2bc.
2023-05-13 Revert "updated image"
    This reverts commit c952793fde73713bad661229f0cd12625c9fa447.
    [OpenUPS_Case.scad]
2023-05-13 Revert "more mini case refinement"
    This reverts commit a3ebdb0b7108780deea73706272cdddaaeca8788.
    [OpenUPS_Case.scad]
2023-05-13 Revert "mini case work"
    This reverts commit 137acbc8cbf3d331e2e1506e5e7c8241f24b06a2.
    [OpenUPS_Case.scad]
2023-05-13 Revert "code cleanup and xt60 creation"
    This reverts commit 32258280bedffabc0b83e3cba687f16b202a1598.
    [OpenUPS_Case.scad]
2023-05-15 moved pcb hole, xt30, fixed sata connectors, fixed heatsink hole, moved terminal blocksand fixed xt30pw-m model.
    [3S1P_Battery_PCB.dxf, 3S2P_Battery_PCB.dxf, OpenUPS_Case.scad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]
2023-05-15 added debug mode
    [OpenUPS_Case.scad]
2023-05-17 adjusted xt30pw-m footprint
    [OpenUPS_Case.scad]
2023-05-17 more xt30pw-m refinements
    [OpenUPS_Case.scad]
2023-05-19 xt30pw-f adjustments
    [OpenUPS_Case.scad]
2023-05-28 added twi.c, twi.h AVR Dx I2C initialization routine that supports both TWI0 and TWI1 in either host or client mode.
2023-05-28 fixed typos in twi.c and twi.h
    [twi.c, twi.h]
2023-05-29 updated ups pcb hole and component locations and the drvebay and mini cases, add thekicad 3d ups pcb model to the gui.
    [OpenUPS_Case.scad]
2023-06-04 increased ups pcb size to 96 x 64, moved holes and updaed cases
    [OpenUPS_Case.scad]
2023-06-04 updated system diagram, adjusted mount hole and projection code.
    [OpenUPS_Case.scad]
2023-06-08 added dual mode, smart mode, pin mux select and other bits to twi_init()
